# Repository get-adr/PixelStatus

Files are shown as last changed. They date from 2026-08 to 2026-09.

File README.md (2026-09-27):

PixelStatus Logo mit Text - Slogan

# Pixel Status (ESP8266 + MAX7219)

Eine physische Statusanzeige für den Schreibtisch: eine rote 32×8-Punktmatrix aus
vier MAX7219-Modulen, angetrieben von einem ESP8266. Sie zeigt vordefinierte Stati
wie „On Air" oder „In a Call", freien Lauftext, einen Countdown-Timer oder die
Uhrzeit. Angesteuert wird sie wahlweise über die eingebaute **Web-Oberfläche**,
per **MQTT** für bestehende Automatisierungen (inkl. automatischer
**Home-Assistant-Erkennung**), oder direkt per **USB-Kabel** ganz ohne WLAN – alle
drei Wege laufen intern über denselben zentralen Befehls-Dispatcher. Ein
Home-Assistant-Setup ist dafür nicht nötig, lässt sich aber ohne weitere
Konfiguration anschließen.

> Hinweis: Der ESP8266 kann **kein Bluetooth** (nur der ESP32). Drahtlos läuft die
> Übertragung über WiFi; alternativ direkt per USB-Kabel (seriell).

Dieses Dokument führt komplett durch das Projekt: Bauteile & Kosten, das
3D-gedruckte Gehäuse, den Zusammenbau, das eingebaute Minispiel „Pixel Attack",
die MQTT-/Home-Assistant-Anbindung und die Companion-App. Wer nur die Firmware
flashen will, kann direkt zu [Firmware einrichten](#firmware-einrichten) springen.

## Funktionen

- **Presets & freier Text** — On Air, In a Call, Busy, BRB per Klick, oder
  eigener Text (statisch oder scrollend, inkl. Umlaute)
- **Timer & Uhrzeit** — Countdown oder Stoppuhr (pausier-/fortsetzbar),
  NTP-synchronisierte Uhr (läuft auch ohne WLAN per manuell gesetzter Zeit)
- **Pixel Attack** — ein kleines Space-Invaders-artiges Easter-Egg direkt auf
  der Matrix, spielbar per Tastatur oder Handy-Touch (siehe
  [eigenes Kapitel](#pixel-attack-spielen))
- **Darstellung** — persistente Helligkeit, 0°/180°-Drehung für kopfüber
  montierte Geräte, wählbare Scrollrichtung
- **Einschalt-Animationen** — Scan-Wipe, Pixel-Fill, oder ein Fortschrittsbalken,
  der live am echten WLAN-Verbindungsaufbau hängt
- **Zwei Zusatz-LEDs** — unabhängig schaltbar, mit Helligkeitsregler,
  Wechselblinken und automatischer Warnung in den letzten Timer-Minuten
- **Akkubetrieb** — 1S-LiPo mit Ladeüberwachung, Live-Prozentanzeige,
  automatische Dimmung bei niedrigem Ladestand; die Stromversorgung des Geräts,
  kein Zubehör (siehe [Bauteile-Liste](#bauteile-liste--ca-kosten))
- **Sicherer Setup-Hotspot** — findet sich kein bekanntes WLAN, öffnet sich ein
  Hotspot mit geräteeigenem, auf der Matrix angezeigtem Passwort
- **Web-UI** — Deutsch/Englisch umschaltbar, automatischer Dark Mode,
  Live-Diagnoseseite (Heap, CPU-Last, WLAN-Signal, Akkuverlauf)
- **MQTT mit Home-Assistant-Autoconfig** — Entitäten für Status, LEDs, Text,
  Helligkeit und Diagnose erscheinen automatisch in HA (siehe
  [eigenes Kapitel](#mqtt--home-assistant-integration))

PixelStatus Infografic

## Komponenten (Software)

### Firmware (dieses Repo, `src/`)

Läuft komplett eigenständig auf dem ESP8266. Sauber in kleine Klassen mit je
einer Verantwortlichkeit aufgeteilt — Anzeige, LEDs, Netzwerk, Uhrzeit, MQTT,
Web-Server und USB-Protokoll laufen alle über denselben zentralen
Befehls-Dispatcher (`Commands.h`), damit sich neues Verhalten nur an einer
Stelle definieren lässt. WLAN- und MQTT-Zugangsdaten sind zur Laufzeit über das
Web-Portal einrichtbar, ganz ohne Neu-Flashen.

### Companion-App ([`companion/`](companion/README.md))

Eine schlanke Tauri-v2-Tray-App für Windows/macOS: Status per Klick aus dem
Menüleisten-Icon setzen, ohne den Browser aufzumachen. Verbindet sich wahlweise
per WLAN oder direkt per USB-Kabel mit demselben Gerät, erkennt Mikrofonnutzung
automatisch und schaltet selbstständig auf „In a Call".

---

## Bauteile-Liste & ca. Kosten

Alle Preise sind grobe Richtwerte für Einzelstücke auf dem üblichen
Bastler-Marktplatz-Niveau (AliExpress/eBay/Amazon), **ohne Versand** — je nach
Anbieter, Region und Bestellmenge kann es deutlich abweichen. Der Akku ist die
Stromversorgung des Geräts (No-Shift-Topologie, siehe
[Aufbau & Verkabelung](#aufbau--verkabelung)) und damit fester Bestandteil der
Liste, kein Zubehör — ohne ihn läuft nur der ESP8266 selbst über USB (zum
Flashen), die Matrix bleibt dunkel. Vollständige Stückliste inkl. Werkzeug
zusätzlich in [`hardware/wiring/parts-list.md`](hardware/wiring/parts-list.md).

| Teil | Menge | ca. Kosten | Hinweis |
|---|---|---|---|
| ESP8266-Board (Wemos D1 mini oder NodeMCU v2) | 1× | 4–6 € | beide Varianten werden von der Firmware unterstützt |
| MAX7219-LED-Matrix 32×8 (4-in-1-Modul) | 1× | 7–10 € | vier MAX7219 onboard durchgekettet, ein 5-poliger Eingang |
| 1S-LiPo, 2000 mAh | 1× | 7–9 € | 51 × 33 × 10 mm |
| TP4056/TP4057-Lademodul | 1× | 1–2 € | Lader + Schutz-IC |
| LDO-Breakout, 3,3 V | 1× | 1–2 € | Versorgung des ESP8266 aus der Akkuschiene |
| Schiebeschalter, geflanscht (z. B. SS-12F15-G070) | 1× | 1–2 € | Haupt-Ein/Aus, Panel-Mount |
| Diode 1N5817, Elko 1000 µF/10 V, Widerstände 100 kΩ/220 kΩ, Keramik-Cs | je 1–2× | 2–3 € | Rückspeisungsschutz, Pufferung, Akku-Spannungsteiler |
| USB-Kabel (Micro-USB oder USB-C, je nach Board) | 1× | 3–5 € | zum Flashen und Laden |
| Dünne Litze / Jumper-Kabel | ein paar | 1–2 € | Brücken zwischen den Modulen |
| Gehäuse (3D-Druck, PLA) | 1 Satz | 2–3 € | reine Filamentkosten, siehe [Gehäuse-Kapitel](#gehäuse-3d-modell--druck) |
| 2× 5-mm-LED + Vorwiderstand (220–330 Ω) | je 1 Satz | ~1 € | optional, aber von der Firmware vorgesehen (Zusatz-LEDs) |

**Summe: ca. 32–45 €**

### Werkzeug (kein Verbrauchsmaterial, meist schon vorhanden)

Lötkolben + Lötzinn, Multimeter (Pflicht vor jedem Einschalten), Seitenschneider
+ Abisolierzange, Schrumpfschlauch oder Isolierband, ein kleiner Schraubendreher
für die Schalter-Befestigung. Details siehe Stückliste oben.

---

## Gehäuse: 3D-Modell & Druck

Das Gehäuse ([`hardware/case/`](hardware/case/)) ist ein **parametrisches
OpenSCAD-Modell** — `case.scad` — entworfen und getestet auf einem **Bambu Lab
P1S in PLA**. Zwei Hauptteile plus ein kleines Zubehörteil:

- **`body`** — Front-Blende und Wanne in einem Stück; alle Komponenten werden
  von **hinten** eingesetzt.
- **`cover`** — Rückdeckel, klippt/reibt auf den Body.
- **`feed_plug`** — kleiner Verschluss-Stopfen für die Kabeldurchführung, durch
  die das Steuerkabel (USB) nach außen geführt wird.

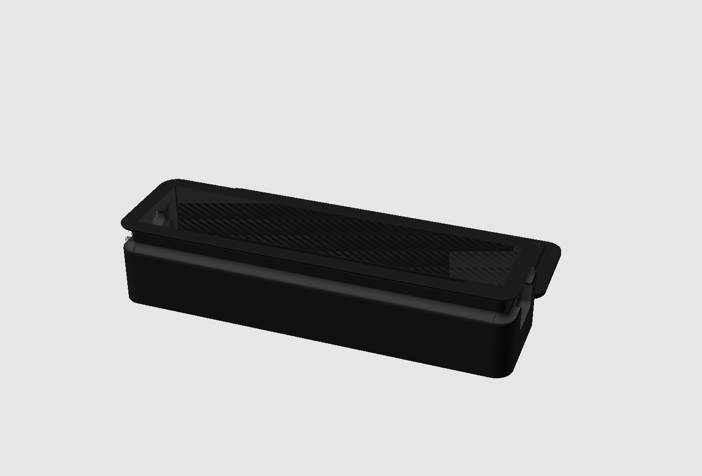
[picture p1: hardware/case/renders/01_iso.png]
Gehäuse-Gesamtansicht


### Ein paar Design-Entscheidungen

- **Druckorientierung**: Der Body druckt mit dem **LED-Fenster nach unten**
  auf dem Druckbett — spart Stützstrukturen genau dort, wo sie die Optik am
  meisten stören würden. Der schräge Ladeteil-Halter (45°) druckt dabei ohne
  eigene Stützen mit.
- **Ladeteil-Halterung**: Eigens konstruierter 45°-Schräghalter — alles hinter
  der Matrix muss strikt hinter deren Bautiefe bleiben, sonst kollidiert es.
- **Kabelaufwicklung**: Ein eingelassener Kragen mit rundem Nutprofil, dazu
  eine Keyhole-Durchführung mit Klemmschlitz als Zugentlastung und dem
  steckbaren `feed_plug` als Verschluss.
- **USB-C-Öffnung**: Stadionform statt scharfem Rechteck, mit Senkung außen
  für den Steckerkörper.
- **Status-LED-Bucht**: Gehäuse eigens verbreitert, damit zwei 5-mm-LEDs im
  Presssitz neben der Matrix Platz finden.
- **Aufstellung**: Bewusst kein Standfuß, keine Wandhalterung — ein
  kompakter, freistehender Baukörper.

| Innenansicht (Ladeteil-Halter) | Halbschnitt | Kabelaufwicklung |
|---|---|---|
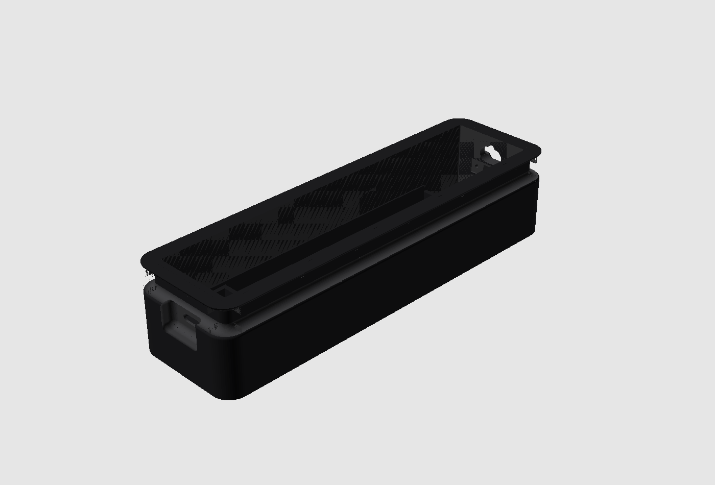
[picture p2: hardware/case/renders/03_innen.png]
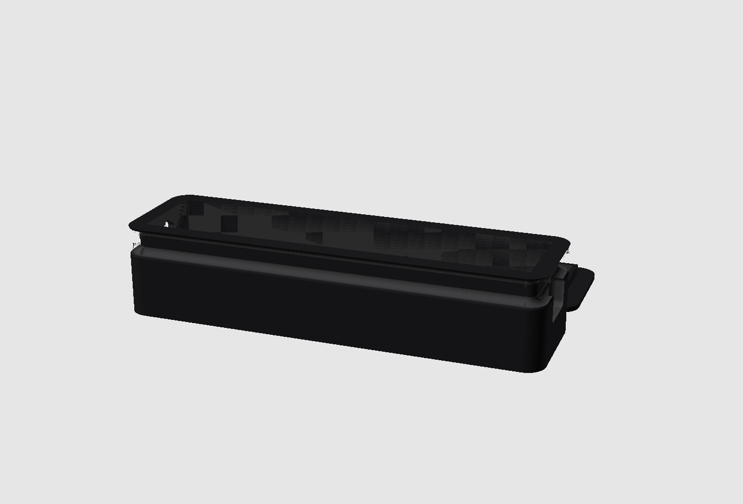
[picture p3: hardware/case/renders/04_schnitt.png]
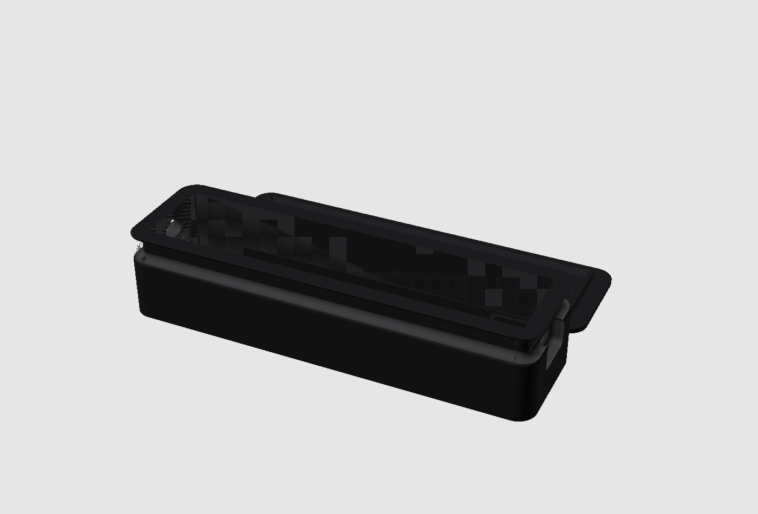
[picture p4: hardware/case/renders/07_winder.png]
|  |  |  |

### Selbst drucken

**Fertige STL-Dateien** liegen schon bereit unter
[`hardware/case/stl/`](hardware/case/stl/) (`body.stl`, `cover.stl`,
`feed_plug.stl`, alternativ als `case.3mf`) — direkt in den Slicer laden, kein
OpenSCAD nötig, solange die Standardmaße passen.

1. **Slicer-Einstellungen**: PLA, Standard-Layerhöhe (0,2 mm reicht), **keine
   Stützstrukturen nötig**, wenn der Body wie oben beschrieben orientiert
   gedruckt wird (bei den meisten Slicern automatisch erkannt, da die flache
   Frontseite dann auf dem Bett liegt).
2. **Passprobe vor dem Verkleben**: Matrix probeweise in den Slot schieben,
   Lademodul in die Tasche legen, Deckel auflegen — noch nichts fest
   verbauen. Bei Klemmen lieber mit Schleifpapier nacharbeiten statt zu
   forcieren (PLA splittert sonst).

**Eigene Maße messen (nur bei abweichenden Bauteilen nötig)**: `case.scad`
markiert alle kritischen Maße (Matrix-Abmessungen, Akku-Größe, Lademodul,
USB-C-Buchse …) mit `(*)` am Zeilenende. Weichen die eigenen Bauteile von den
hinterlegten Werten ab, dort mit dem Messschieber nachmessen, anpassen und neu
rendern:

```bash
# OpenSCAD installieren (einmalig)
brew install openscad          # oder von openscad.org

# STL exportieren (aus hardware/case/)
openscad -o stl/body.stl -D 'part="body"' case.scad
openscad -o stl/cover.stl -D 'part="cover"' case.scad
openscad -o stl/feed_plug.stl -D 'part="feed_plug"' case.scad

# Vorschau-Renderbilder neu erzeugen (wie oben im Dokument)
./render.sh
```

---

## Aufbau & Verkabelung

Die Matrix hängt direkt an der Akkuschiene (No-Shift-Topologie, ≤ ~4,5 V —
läuft ohne Pegelwandler an der 3,3-V-SPI des ESP8266), der ESP8266 selbst über
einen LDO+Diode am selben Zweig. **USB am D1 mini allein reicht nicht**, um das
Gerät normal zu betreiben: ohne Akku bzw. bei ausgeschaltetem Hauptschalter
läuft darüber nur der ESP selbst (zum Flashen/Debuggen) — die Matrix bleibt
dunkel, weil ihre Stromversorgung am abgeschalteten Akku-Zweig hängt (eine
Schottky-Diode verhindert dabei sogar ausdrücklich, dass USB-Strom in diesen
Zweig zurückfließt). Für den Normalbetrieb sind Akku und Hauptschalter also
notwendig, nicht optional.

### Signal-Pins (SPI)

| MAX7219 | ESP8266 (NodeMCU / D1 mini) |
|---|---|
| VCC | Akkuschiene (SYS, **nicht** an einen 5-V-Pin) |
| GND | Stern-Masse |
| DIN | D7 / GPIO13 (MOSI, HW-SPI) |
| CLK | D5 / GPIO14 (SCK, HW-SPI) |
| CS | D8 / GPIO15 (`CS_PIN`) |

DIN und CLK liegen fest auf den Hardware-SPI-Pins. CS ist in `include/config.h`
frei wählbar. Die zwei Zusatz-LEDs hängen an `LED_PIN_1`/`LED_PIN_2` (Default
GPIO4/D2 und GPIO5/D1) über je einen Vorwiderstand gegen GND.

### Vollständige Montageanleitung

Für die komplette Verkabelung gibt es eine eigene, ausführliche Anleitung mit
Verkabelungsdiagramm und nummerierter Lötreihenfolge:
[`hardware/wiring/wiring-sheet.html`](hardware/wiring/wiring-sheet.html)
(im Browser öffnen). Kurzfassung der fünf Phasen:

1. **Gehäuse vorbereiten** — Druckgrat entfernen, Passprobe, Schalter
   final verschrauben.
2. **Löten (Werkbank)** — acht Schritte in fester Reihenfolge: LDO →
   Rückspeisungsschutz-Diode → Akku-Spannungsteiler (für die
   Prozentanzeige) → Lademodul → Matrix-Stützkondensatoren → Hauptschalter
   in die Leistungsleitung → Stern-Masse zusammenführen → SPI verdrahten.
3. **Bench-Test** — **außerhalb** des Gehäuses, mit dem Multimeter
   gegenprüfen (Kurzschluss, Diodenpolung, Stern-Masse), bevor überhaupt der
   Akku angeschlossen wird. Fehler sind hier leicht zu finden; im
   geschlossenen Gehäuse wird jede Korrektur mühsam.
4. **Endmontage ins Gehäuse** — siehe unten.
5. **Firmware-Erstkonfiguration** — WLAN über den Setup-Hotspot einrichten,
   `BATTERY_MONITOR_ENABLED` aktivieren, neu flashen.

### Wie alles ins Gehäuse kommt

Reihenfolge für die Endmontage (Body wird von **hinten** befüllt):

1. Nochmals auf Kurzschluss/Wackelkontakt prüfen, bevor irgendetwas fest im
   Gehäuse verschwindet.
2. **Matrix von hinten in den Slot schieben**, bis zum Anschlag an der
   Lader-seitigen Wand — sitzt im Sandwich zwischen Front und Deckel, kein
   Kleben nötig.
3. **Zusatz-LEDs von hinten in die Front-Löcher drücken** (Presssitz durch
   die LED-Bucht).
4. **Lademodul in die Tasche legen** — USB-C-Buchse sitzt in der
   Stirnwand-Öffnung, die Platine wird über die verlöteten Kabel gehalten.
5. **ESP8266 + restliche Elektronik** (LDO, Diode, Spannungsteiler) lose im
   Rückraum platzieren, offene Lötstellen mit Schrumpfschlauch isolieren.
6. **LiPo-Akku einlegen**, flach im Rückraum, mit kurz genug bemessenem Kabel
   zum Lademodul (Zugentlastung).
7. **Steuerkabel durch die Durchführung fädeln**, in den Klemmschlitz
   drücken, restliche Länge in der umlaufenden Nut aufwickeln, danach den
   `feed_plug` im Presssitz einsetzen.
8. **Deckel aufsetzen** — Reib-/Klipplippe, gleichmäßig andrücken.
9. **Funktionstest im geschlossenen Gehäuse**: Schalter Ein, Matrix und beide
   LEDs prüfen; danach Schalter Aus + Laden testen (Gerät bleibt dabei aus,
   USB-C am Lader lädt trotzdem).

| USB-C-Öffnung | Kabeldurchführung + Stopfen | Status-LED-Bucht |
|---|---|---|
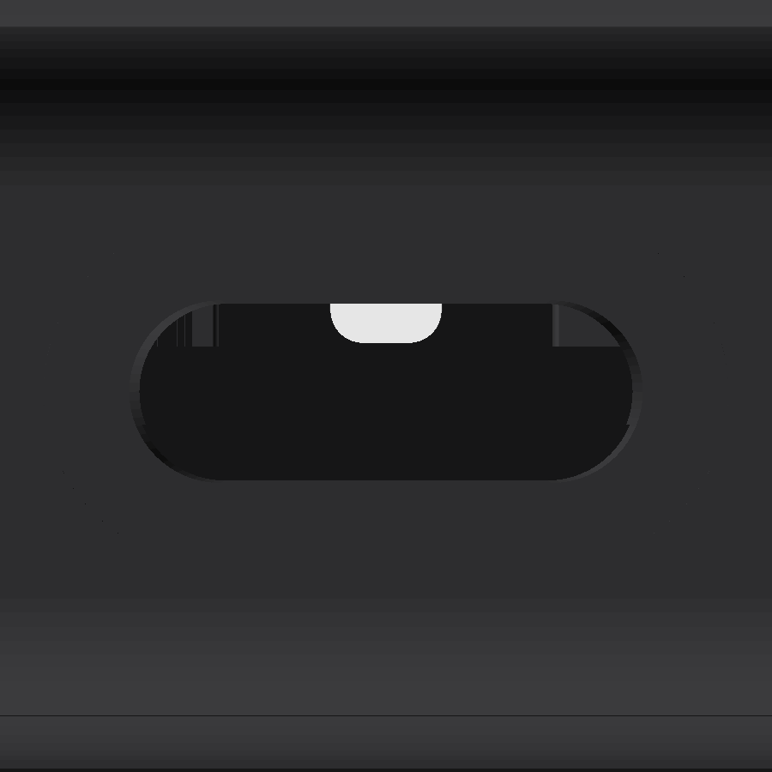
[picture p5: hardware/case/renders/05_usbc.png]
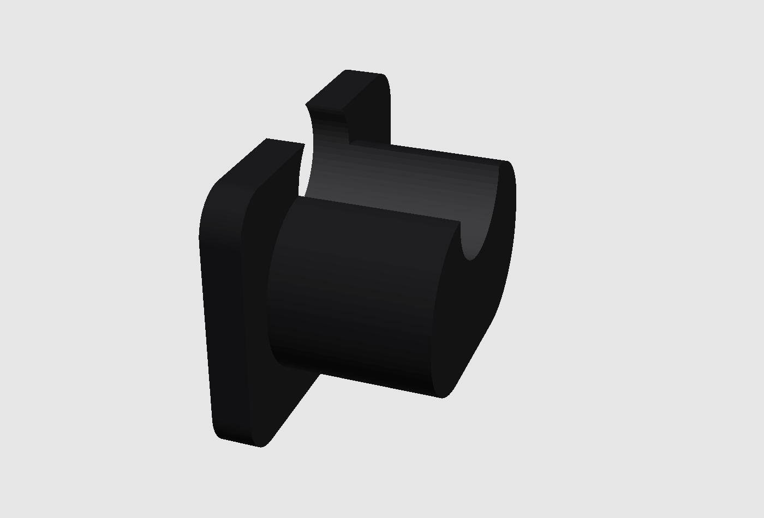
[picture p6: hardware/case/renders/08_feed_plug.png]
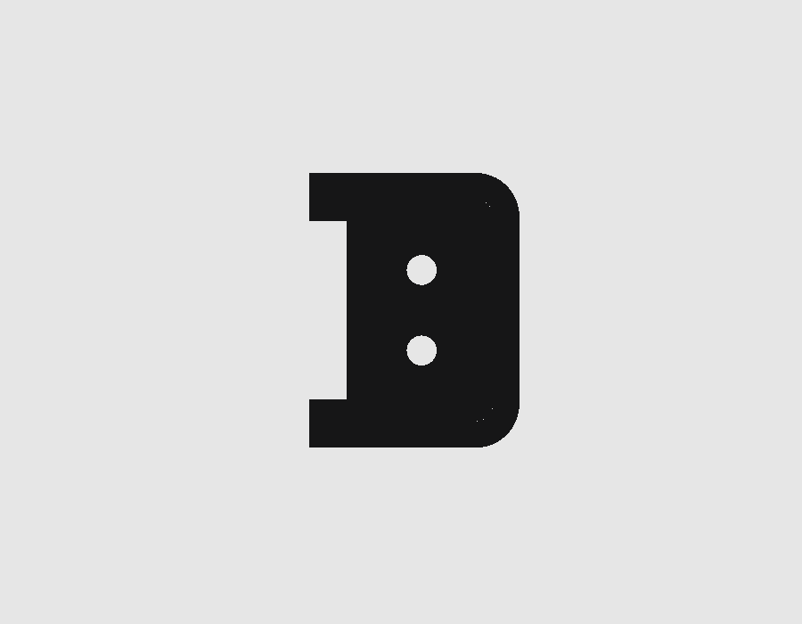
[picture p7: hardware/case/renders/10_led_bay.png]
|  |  |  |

## Firmware einrichten

```bash
# PlatformIO installieren (einmalig)
brew install platformio          # oder: pip install platformio

# Konfiguration anlegen und WiFi/MQTT eintragen
cp include/config.example.h include/config.h

# Bauen, flashen, Logs ansehen
pio run                          # kompilieren
pio run -t upload                # auf den ESP8266 flashen
pio device monitor               # serielle Ausgabe (115200 Baud)
```

Für den Wemos D1 mini: `pio run -e d1_mini -t upload`.

### Apple Silicon: Bauen im Container

Die Xtensa-Toolchain für den ESP8266 gibt es für macOS **nur als x86-Binary** —
weder der ESP8266-Arduino-Boardindex noch die PlatformIO-Registry bieten einen
arm64-Build an, und das Projekt dahinter (`esp-quick-toolchain`) hat seit Anfang
2023 kein Release mehr. Auf Apple Silicon lief das bisher über Rosetta; ohne
Rosetta scheitert `pio run` mit „Bad CPU type in executable". Für Linux gibt es
die Toolchain dagegen als `aarch64`-Build — in einem arm64-Linux-Container läuft
sie nativ, ohne Emulation:

```bash
brew install --cask orbstack      # oder Docker Desktop / colima
brew install esptool              # nativer Flasher für macOS

tools/build-docker.sh             # baut d1_mini im Container
tools/build-docker.sh nodemcuv2   # andere Env
tools/flash.sh                    # flasht die gebaute .bin vom Mac aus
pio device monitor                # Logs weiterhin nativ (reines Python)
```

Gebaut wird im Container, **geflasht vom Mac** — USB-Geräte lassen sich auf
macOS nicht in die Linux-VM durchreichen, der Upload braucht aber auch keinen
Compiler. Die fertige `.bin` landet über das gemountete Projektverzeichnis
direkt im Arbeitsverzeichnis. Framework und Toolchain liegen in einem benannten
Docker-Volume, nur der erste Lauf lädt sie herunter.

Zum Flashen reicht das USB-Kabel am D1 mini; für den eigentlichen Betrieb
danach Akku anschließen und den Hauptschalter einschalten (siehe
[Aufbau & Verkabelung](#aufbau--verkabelung)) — die Matrix bleibt sonst dunkel.
Nach dem Flashen scrollt das Display die IP-Adresse. Bedienseite öffnen unter
`http://pixelstatus.local` oder über die angezeigte IP. Findet sich beim ersten
Boot kein bekanntes WLAN, öffnet das Gerät selbst einen Setup-Hotspot mit
eigenem Passwort (wird auf der Matrix angezeigt) — WLAN-Zugangsdaten dann unter
`http://192.168.4.1/wifi` eintragen.

PixelStatus - Montiert

---

## Pixel Attack spielen

Ein kleines Space-Invaders-artiges Easter-Egg direkt auf der 32×8-Matrix: ein
Verteidiger am rechten Rand weicht Angreifern aus, die von links hereinlaufen
und beschossen werden. Rein clientseitig über die Web-UI gesteuert (keine
physischen Tasten am Gerät, kein MQTT/USB-Befehl dafür vorgesehen).

### Am Rechner (Browser, Tastatur)

Auf der Startseite die Kachel **„Pixel Attack"** öffnen, dann **„Start"**
klicken. Steuerung wahlweise über die Panel-Buttons (▲ / ▼ / ●) oder direkt per
Tastatur, solange das Panel geöffnet ist:

| Taste | Aktion |
|---|---|
| ↑ / ↓ (Pfeiltasten) | Verteidiger hoch/runter bewegen |
| Leertaste | Schießen (bis zu 5 Schüsse gleichzeitig unterwegs) |
| B | Bombe zünden (2 pro Runde, sprengt alle sichtbaren Angreifer — an die zwei physischen Zusatz-LEDs gekoppelt, die anzeigen, wie viele Bomben noch verfügbar sind) |

Punkte gibt's pro Treffer, größere Angreifer brauchen mehrere Treffer. Bei 0
Leben läuft „GAME OVER", der erreichte Score und der Highscore als
Lauftext über die Matrix.

### Am Handy (Touch-Steuerung)

Im Spiel-Panel gibt es zusätzlich einen Button **„Touch-Steuerung"**, der die
eigene Seite `/play` in einem neuen Tab öffnet — für Handys im **Querformat**
gedacht: große Daumen-Buttons links (Hoch/Runter) und rechts (Feuer/Bombe), in
der Mitte Score/Leben/Bomben/Highscore plus ein Neustart-Button. Im
Hochformat blendet die Seite einen Hinweis zum Drehen ein.

Die Seite nutzt dieselbe API wie das Desktop-Panel — keine gesonderte
Konfiguration nötig, einfach auf demselben WLAN mit dem Handy öffnen (URL vom
Gerät wie oben, z. B. `http://pixelstatus.local/play`).

Pixel_Attack

---

## MQTT & Home-Assistant-Integration

### MQTT-Grundlagen

MQTT lässt sich zur Laufzeit über das Web-Portal (`/settings` → Tab „MQTT")
ein-/ausschalten und konfigurieren — Broker-Host, Port, Zugangsdaten und
Basis-Topic, alles ohne Neu-Flashen. Befehle gehen an
`<base>/cmd/<aktion>` (Basis-Topic frei wählbar, Default `pixelstatus`):

```
pixelstatus/cmd/preset      onair
pixelstatus/cmd/text        Hallo Welt
pixelstatus/cmd/scroll      Langer Lauftext
pixelstatus/cmd/timer       300        # Countdown in Sekunden; "up"; "pause"; "resume"; "stop"
pixelstatus/cmd/brightness  8
pixelstatus/cmd/led         1 on       # "1|2|both" + "off|on|blink"
pixelstatus/cmd/clear
```

Der aktuelle Gesamtzustand wird **retained** nach `pixelstatus/state`
veröffentlicht — auch bei Änderungen über die Web-UI oder USB, nicht nur bei
MQTT-Kommandos. Ein `pixelstatus/health`-Topic ergänzt Diagnosewerte (freier
Speicher, WLAN-Signal, Laufzeit, optional Akkuspannung/-prozent). MQTT lässt
sich in `include/config.h` per `MQTT_ENABLED false` auch als Compile-Time-
Default ganz abschalten.

### Automatische Home-Assistant-Erkennung (MQTT Discovery)

Sobald MQTT aktiv und mit einem Broker verbunden ist, meldet sich das Gerät
automatisch bei Home Assistant per [MQTT-Discovery](https://www.home-assistant.io/integrations/mqtt/#mqtt-discovery) —
**keine YAML-Konfiguration, keine manuellen Entitäten nötig.** Alles erscheint
gruppiert unter einem gemeinsamen Gerät „pixelstatus":

| Entität | Typ | Beschreibung |
|---|---|---|
| Status | Select | Presets: On Air, Call, Busy, BRB, Free, Off |
| Text | Text | eigener, frei einstellbarer Anzeigetext |
| Matrix-Helligkeit | Number | 0–15 Stufen |
| LED 1 / LED 2 | Light | An/Aus, Helligkeit (0–15), Effekt „Blinken" |
| Freier Speicher, WLAN-Signal, Laufzeit | Sensor | Diagnosewerte |
| Akkuspannung, Akkustand | Sensor | nur sichtbar, wenn die optionale Akku-Hardware aktiviert ist |
| Countdown-Warnung | Binary Sensor | aktiv während der letzten Timer-Minuten |

Alle Entitäten (außer dem Status-Select, der bewusst ohne Rückkanal arbeitet,
da sich der Anzeigeinhalt nicht immer eindeutig auf einen Preset-Namen
zurückrechnen lässt) zeigen den **echten Live-Zustand** — egal ob die letzte
Änderung über Home Assistant, die Web-UI, die Companion-App oder USB kam. Das
Gerät meldet sich zudem über ein MQTT-Last-Will automatisch als „nicht
verfügbar", falls die Verbindung ungeplant abreißt (Stromausfall, WLAN weg).

**Einrichtung**: einfach unter `/settings` → „MQTT" den eigenen Broker
eintragen (Host, Port, ggf. Zugangsdaten) und speichern — Home Assistant
übernimmt den Rest automatisch, sobald es denselben Broker kennt.

---

## Companion-App

Eine schlanke Tray-/Menüleisten-App für **Windows und macOS**
([`companion/`](companion/README.md), gebaut mit Tauri v2): Status per Klick
setzen, ohne den Browser aufzumachen. Läuft komplett unabhängig von MQTT/Home
Assistant — spricht direkt mit dem Gerät.

### Verbindungsoptionen

Umschaltbar in den Einstellungen der App, wird dort dauerhaft gespeichert:

- **WiFi (HTTP)** — verbindet sich wie die Web-UI über das lokale Netzwerk,
  Standard-Host `pixelstatus.local` (oder die IP direkt eintragen). Funktioniert
  von überall im selben WLAN.
- **USB-Kabel (seriell)** — spricht dasselbe Protokoll wie der Web-API-Weg,
  aber direkt über die USB-Verbindung, ganz ohne WLAN. Seriellen Port aus einer
  Liste wählen (↻ aktualisiert sie); für Windows wird der CH340-Treiber des
  D1 mini benötigt (macOS bringt ihn meist schon mit), die App zeigt dazu einen
  Hinweis mit Download-Link. Das reine Öffnen des Ports löst am D1 mini **keinen**
  Reset aus — Steuerung läuft also ohne Neustart des Geräts.

Beide Wege nutzen intern dieselben Aktionen wie `src/Commands.h` — welcher Weg
gerade aktiv ist, ändert am Verhalten nichts.

### Bedienung

- **Tray-Menü**: Presets direkt anklickbar (On Air, In a Call, Busy, BRB,
  Uhrzeit, Aus), der aktive Status ist mit einem Häkchen markiert — auch wenn
  er von woanders (Web-UI, MQTT, Home Assistant) gesetzt wurde, die App pollt
  den Gerätezustand im Hintergrund mit.
- **Fenster** (über „Einstellungen…" im Tray-Menü): zusätzlich eigener Text,
  Timer (Play/Pause/Stopp, Countdown oder Hochzählen), Matrix- und
  LED-Helligkeit, sowie sämtliche Geräte-Einstellungen (System/LED/WiFi/MQTT) —
  dasselbe `get*`/`cfg*`-Protokoll wie im Web-Portal, funktioniert also über
  **beide** Verbindungsarten. Fenster-Schließen versteckt nur (App bleibt im
  Tray), Beenden über das Tray-Menü.
- **Automatischer Status**: Checkbox „Automatisch „In a Call" bei
  Mikrofonnutzung" — die App erkennt Mikrofonzugriff (macOS über CoreAudio ohne
  Berechtigungsabfrage, Windows über die Registry) und schaltet selbstständig
  um; beim Auflegen kehrt der zuvor manuell gesetzte Status zurück.
- **Sprache**: Deutsch/Englisch umschaltbar, gilt auch fürs Tray-Menü.

### Installation

Vorgefertigte Installer (Windows x64/ARM64, macOS) baut die GitHub-Action bei
jeder Änderung unter `companion/` automatisch als Artifact. Alternativ selbst
bauen:

```bash
cd companion
npm install
npm run tauri icon pfad/zu/icon.png   # einmalig: Icons erzeugen
npm run tauri dev                      # Entwicklungsmodus
npm run tauri build                    # Installer: .dmg / .exe
```

Details (Voraussetzungen, macOS-Gatekeeper-Hinweis „ist beschädigt" bei
unsignierten Downloads, Projektaufbau) siehe
[`companion/README.md`](companion/README.md).

---

## Weitere Steuerwege (Referenz)

### Web-API (HTTP GET)

| Endpunkt | Beispiel |
|---|---|
| Generisch | `/api/cmd?action=preset&value=onair` (von der Companion-App genutzt) |
| Preset | `/api/preset?name=onair` (onair, call, busy, brb, dnd, free, away, off) |
| Text | `/api/text?msg=Hallo&scroll=1` |
| Timer | `/api/timer?seconds=300&dir=down` · `?dir=up` · `?stop=1` |
| Helligkeit | `/api/brightness?level=8` (0–15) |
| Leeren | `/api/clear` |
| Status | `/api/state` (JSON) |

Uhrzeit zeigen: `/api/cmd?action=clock&value=on`. Zeitquelle (NTP an/aus,
Server) **und Zeitzone** stehen im System-Tab der Einstellungen; `NTP_TZ`/
`NTP_SERVER` in `config.h` sind nur die Startwerte. Übertragen wird immer ein
UTC-Zeitstempel – die eingestellte Zone bestimmt, was die Matrix daraus macht.

### USB (seriell, 115200 Baud)

Ohne WiFi steuerbar – zeilenweise Befehle `<aktion> <wert>` auf den USB-Port,
Antwort ist eine JSON-Statuszeile:

```
preset onair
text Hallo Welt
timer 300            # Countdown in Sekunden; "up"; "pause"; "resume"; "stop"
clock on
settime 1719600000   # Systemzeit setzen (Uhr ohne WiFi/NTP)
brightness 8
clear
```

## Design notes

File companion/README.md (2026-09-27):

# Pixel Status Companion

Tray-/Menüleisten-App (Windows + macOS) zum Steuern des ESP8266-Pixel-Status-Displays.
Gebaut mit **Tauri v2** (Rust-Backend + HTML/JS-Frontend). Steuert das Display
wahlweise über **WiFi (HTTP)** oder das **USB-Kabel (seriell)** – umschaltbar in
den Einstellungen.

## Voraussetzungen

- **Node.js** (vorhanden) – liefert die Tauri-CLI über npm.
- **Rust** – noch installieren:
  ```bash
  curl --proto '=https' --tlsv1.2 -sSf https://sh.rustup.rs | sh
  ```
- Plattform-Abhängigkeiten für Tauri v2 siehe https://tauri.app/start/prerequisites/
  (macOS: Xcode Command Line Tools; Windows: WebView2 + MSVC Build Tools).

## Icons (einmalig vor dem ersten Build)

Tauri bettet App-/Tray-Icons ein, daher müssen sie existieren. Aus einem
beliebigen quadratischen PNG generieren:

```bash
npm install
npm run tauri icon pfad/zu/icon.png   # erzeugt src-tauri/icons/*
```

## Entwickeln & Bauen

```bash
npm install
npm run tauri dev      # App im Entwicklungsmodus starten
npm run tauri build    # Installer bauen: macOS .dmg / Windows .exe (nsis)
```

### Abhängigkeiten und Dependabot

Die App wird ausschließlich für **Windows und macOS** gebaut (siehe Workflow
unten). Tauri zieht seine Linux-Abhängigkeiten (`gtk`, `glib`, `webkit2gtk`,
`libappindicator` …) trotzdem in `Cargo.lock`, sie werden aber nur für
Linux-Ziele überhaupt kompiliert:

```bash
cargo tree -e normal -i glib --target x86_64-unknown-linux-gnu   # Treffer: gtk 0.18 -> tao/muda/tray-icon
cargo tree -e normal -i glib --target aarch64-apple-darwin       # "nothing to print"
```

Eine Dependabot-Meldung zu einem dieser Crates betrifft daher keinen
ausgelieferten Build. Sie lässt sich zudem nicht durch ein Update auflösen:
Tauri 2.x hängt über `tao`/`muda`/`tray-icon` fest an `gtk` 0.18 (gtk3-rs), das
seinerseits `glib` 0.18 vorgibt — ein Sprung auf `glib` 0.20 setzt ein
Upstream-Update von Tauri voraus. Vor dem Schließen einer solchen Meldung beide
`cargo tree`-Aufrufe oben wiederholen, statt die Einschätzung fortzuschreiben.

## Installation vorgefertigter Builds (GitHub Actions)

Der Workflow `.github/workflows/companion-build.yml` baut bei jedem Push nach
`main` (mit Änderungen unter `companion/`) automatisch Installer für Windows
x64/ARM64 und macOS als Artifacts.

**macOS: „ist beschädigt und kann nicht geöffnet werden“** – kein echter
Schaden, sondern Gatekeeper: die App ist **nicht mit einer Apple-Developer-ID
signiert/notarisiert**, und der Browser markiert heruntergeladene Dateien mit
dem Quarantäne-Flag (`com.apple.quarantine`). Statt der eigentlich
zutreffenden Meldung „von nicht verifiziertem Entwickler“ zeigt macOS in
diesem Fall fälschlich „beschädigt“. Fix nach der Installation:

```bash
xattr -cr "/Applications/Pixel Status Companion.app"
```

Danach lässt sich die App normal öffnen. Muss nach jedem neuen Download eines
Builds wiederholt werden. Dauerhaft beheben ließe sich das nur durch Code-
Signing + Notarisierung (Apple-Developer-Programm, 99 $/Jahr, plus
Zertifikat-Secrets im CI-Workflow) – für den privaten Gebrauch nicht
eingerichtet.

## Bedienung

- Die App lebt in der Menüleiste/Tray. Das Menü bietet die Presets direkt
  (On Air, In a Call, Busy, BRB, Uhrzeit, Aus) sowie „Einstellungen…“.
- Das Fenster (über „Einstellungen…“) bietet zusätzlich freien Text, Timer,
  Helligkeit und die Verbindungseinstellungen. Fenster-Schließen versteckt nur
  (App bleibt im Tray); Beenden über das Tray-Menü.
- **Verbindung** in den Einstellungen: WiFi (Host, Standard `pixelstatus.local`)
  oder USB (seriellen Port wählen, ↻ aktualisiert die Liste). Wird im
  App-Config-Verzeichnis persistiert.
- **Auto-Status:** In den Einstellungen lässt sich die automatische Statusquelle
  wählen. Bei Mikrofon-Nutzung pollt die App die Mikrofonnutzung und schaltet
  bei Aktivität auf
  „In a Call"; beim Auflegen wird der zuvor manuell gesetzte Status
  wiederhergestellt (sonst geleert).
  - macOS: über CoreAudio (`kAudioDevicePropertyDeviceIsRunningSomewhere`) —
    erkennt jede Mikrofonnutzung, **ohne** Mikrofon-Berechtigung anzufordern.
  - Windows: über die Registry (`CapabilityAccessManager\ConsentStore`).

### Microsoft-Teams-Präsenz

Als automatische Statusquelle kann „Microsoft Teams“ gewählt werden. Die App
verwendet Microsoft Graph (`GET /me/presence`) und bietet zwei Login-Methoden
(Einstellungen → „Login-Methode“):

- **Browser (empfohlen, Default):** Authorization-Code-Flow mit PKCE. Die App
  hört kurz auf `127.0.0.1:8939`, öffnet den Systembrowser auf der Anmelde-URL
  und tauscht den zurückgelieferten Code gegen Tokens ein. Die passende
  Loopback-URI muss in der App-Registrierung eingetragen sein. Ein erneuter
  Klick auf „Anmelden“ bricht einen noch wartenden Vorgang ab und gibt den
  Port sofort wieder frei.
- **Device-Code:** gerätecodebasierter Login (Code im Browser eingeben), der in
  vielen Tenants gesperrt ist — als Option für Tenants, die ihn erlauben.

Dafür muss eine Microsoft-Entra-App-Registrierung als Public Client mit
delegierter Berechtigung `Presence.Read` angelegt und deren Client-ID
eingetragen werden; als Tenant ist `organizations` für Arbeits-/Schulkonten
voreingestellt. Die Registrierung lässt sich einmalig mit dem Helper-Skript im
Repo anlegen (läuft selbst per Browser-Login):

```powershell
pwsh tools/New-PixelStatusAppRegistration.ps1 -InstallModules
```

Es legt die App an, setzt `Presence.Read` und die Loopback-URI und gibt die
Client-ID aus, die in die Einstellungen eingetragen wird. Für das Erstellen und
Aktualisieren von App-Registrierungen gibt es keinen passenden delegierten
`Application.ReadWrite.OwnedBy`-Scope; der Helper benötigt deshalb
`Application.ReadWrite.All`. Es werden keine weiteren Graph-Berechtigungen
angefordert. Die Anmeldung muss von einem Konto erfolgen, das im Tenant
App-Registrierungen verwalten darf.

Access- und Refresh-Tokens werden nicht in `settings.json` gespeichert, sondern
im nativen Credential Store des Betriebssystems. `InACall`/`InAMeeting` werden
zu „In a Call“, `Busy` zu „Busy“, `DoNotDisturb` zu „DND“, `BeRightBack` zu
„BRB“, `Away` zu „Away“ und `Available` zu „Frei“ (Matrix: `FREE`) abgebildet.

Die Präsenz wird im Hintergrund alle 10 s abgefragt; ans Display geht nur eine
Änderung. Ist Teams als Quelle gespeichert, zeigt das Fenster über den
Status-Buttons Login-Status und aktuelle Präsenz und markiert den zugeordneten
Button mit einem „Teams“-Badge (unabhängig von der grünen Markierung, die den
tatsächlichen Display-Inhalt zeigt). Das Fenster nutzt dafür das Ergebnis der
Hintergrundabfrage und fragt Graph nicht zusätzlich ab.
Schlägt eine Graph-Abfrage fehl (z. B. bei beendetem Teams oder
Netzwerkproblemen), meldet Graph `Offline` oder keinen Verfügbarkeitswert,
schaltet die App die Matrix sofort einmalig aus und zeigt einen Hinweis.
Weitere Fehl- bzw. Offline-Meldungen überschreiben manuelle Bedienung nicht;
sobald wieder eine zuordenbare Teams-Präsenz vorliegt, zeigt die Matrix deren
Status. Andere unbekannte Werte lassen die Anzeige unverändert.

## Aufbau

| Datei | Zweck |
|---|---|
| `src/` | Frontend (index.html, main.js, styles.css), nutzt globales `window.__TAURI__` |
| `src-tauri/src/lib.rs` | Tray-Menü, Tauri-Commands, App-State |
| `src-tauri/src/transport.rs` | HTTP- und USB-Seriell-Versand, Port-Liste |
| `src-tauri/src/settings.rs` | Laden/Speichern der Einstellungen als JSON |
| `src-tauri/src/mic.rs` | Mikrofon-Nutzungserkennung (macOS/Windows) für den Auto-Status |

Alle Befehle gehen am Ende auf den Firmware-Endpunkt `/api/cmd?action=&value=`
(HTTP) bzw. die serielle Zeile `<action> <value>` – dieselben Aktionen wie in
`../src/Commands.h`.

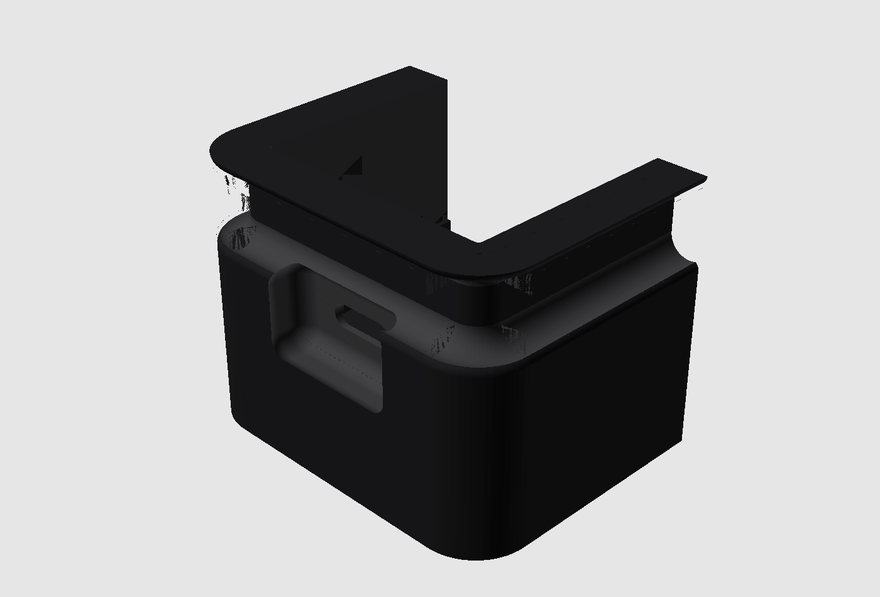
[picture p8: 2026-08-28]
hardware/case/renders/09_coupon_chg.png

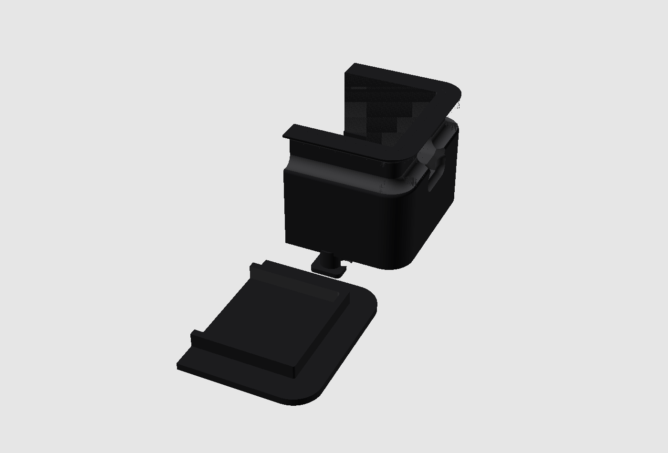
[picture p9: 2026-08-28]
hardware/case/renders/06_coupon.png

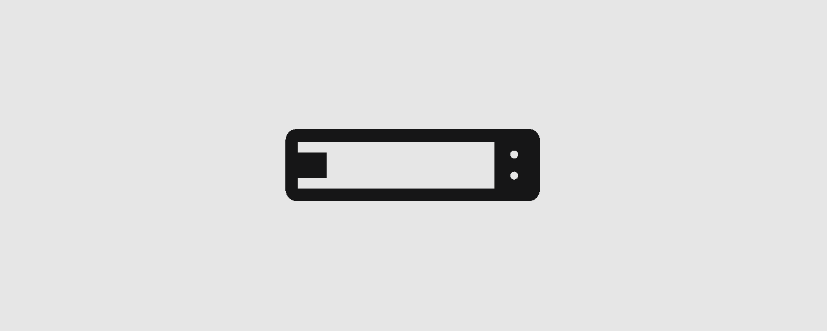
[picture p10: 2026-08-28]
hardware/case/renders/02_front.png

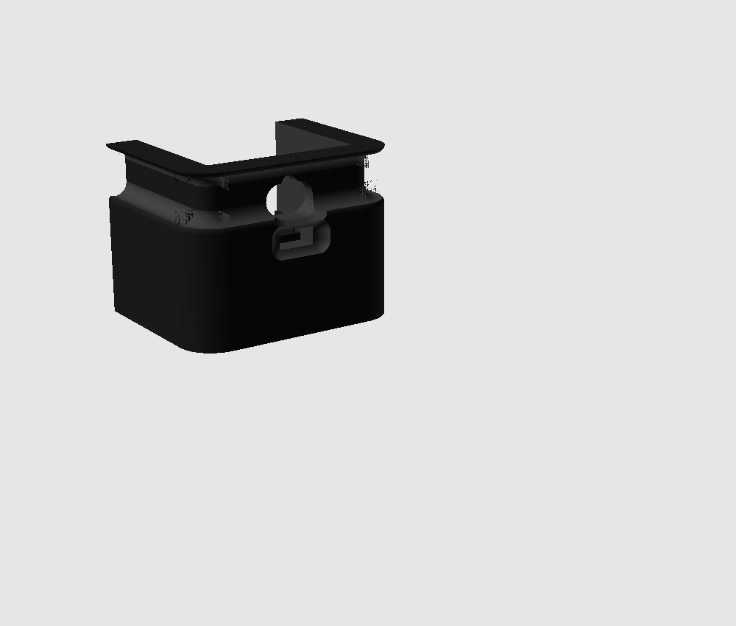
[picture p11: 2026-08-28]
hardware/case/renders/11_switch.png

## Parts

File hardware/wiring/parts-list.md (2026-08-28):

# Teileliste — Akkubetrieb (1S-LiPo, No-Shift-Topologie)

Vollständige Teileliste für den Akkubetrieb. Montageanleitung + Verkabelungsblatt:
siehe `hardware/wiring/wiring-sheet.html`.

## Vorhanden (vollständig)

| Teil | Menge | Zweck | Details |
|---|---|---|---|
| 1S-LiPo, 2000 mAh | 1× | Energiespeicher | 51 × 33 × 10 mm |
| TP4057-Lademodul | 1× | Lader + Schutz-IC | Silk „LX-LBES", Pins IN±/BAT±/OUT± |
| LDO-Breakout | 1× | 3,3-V-Versorgung ESP | SOT23-5 „N1F", Silk „V987", 3-Pin Vi/GND/Vo — **Vo = 3,3 V gemessen/bestätigt** |
| Master-Schalter SS-12F15-G070 | 1× | Ein/Aus, gesamtes Gerät | Panel-Mount, für −X-Stirnwand vorgesehen (siehe Gehäuse) |
| ESP8266 D1 mini | 1× | Steuerung | |
| MAX7219-Matrix, 4× | 1 Modul | Anzeige | 32×8 |
| Elko 1000 µF / 10 V | 1× | Matrix-V_CC-Pufferung (Bulk) | Spannungsfestigkeit 10 V gewählt für Reserve über max. 4,2 V LiPo-Spannung |
| 1N5817 | 1× | Rückspeisungsschutz LDO-`Vo` → ESP-`3V3` bei gleichzeitigem USB | bedrahtet, DO-41, 1 A / 20 V, Vf ≈ 0,45 V @ 1 A |
| Keramik-C 100 nF | 2× | 1× Matrix-V_CC-Decoupling, 1× Stabilisierung A0-Spannungsteiler | |
| Widerstand 100 kΩ, 1% | 1× | A0-Spannungsteiler, R1 (Akku `OUT+` → A0) | |
| Widerstand 220 kΩ, 1% | 1× | A0-Spannungsteiler, R2 (A0 → GND) | |
| Status-LEDs 5 mm | 2× | LED-Bucht im Gehäuse | rot + grün (Standardfarben, austauschbar) |
| Vorwiderstand 220–330 Ω | 2× | je 1× pro Status-LED | |
| Gehäuse (3D-Druck) | body + cover + feed_plug | fertig gedruckt, Passung bestätigt (17. August 2026) | siehe `hardware/case/` |
| M2-Schrauben, selbstschneidend | 2× | Schalter-Flansch an −X-Wand | Raster 15 mm, Löcher ø2,2 vorbereitet |

## Werkzeug & Verbrauchsmaterial (für die Montage, nicht Teil der Stückliste)

- Lötkolben + Lötzinn, Entlötlitze/Absaugpumpe für Korrekturen
- Multimeter (Spannung + Durchgangsprüfung — vor jedem Einschalten Pflicht)
- Schrumpfschlauch (mehrere Durchmesser) oder Isolierband für blanke Lötstellen
- Seitenschneider + Abisolierzange
- Kleiner Kreuzschlitz- oder Sechskant-Schraubendreher für die M2-Schalterschrauben
- Etwas dünne Litze (verschiedenfarbig empfohlen: rot/schwarz/gelb) für die kurzen Brücken zwischen den Modulen
- Optional: Heißkleber als Zugentlastung für Kabel an den Modul-Lötpads

## A0-Spannungsteiler — Auslegung

Schaltung: `OUT+` (Akku) → R1 (100 kΩ) → **A0** → R2 (220 kΩ) → GND

Teilerfaktor R2/(R1+R2) = 220/320 = **0,6875**

D1-mini-A0-Limit: ≤ 3,2 V

| Akkuspannung | Spannung an A0 |
|---|---|
| 4,2 V (voll) | 2,89 V |
| 3,7 V (nominal) | 2,54 V |
| 3,0 V (leer) | 2,06 V |

Reserve bei voller Ladung: ~0,3 V unter dem A0-Limit.

Stromverbrauch des Teilers: 4,2 V / 320 kΩ ≈ **13 µA** (vernachlässigbar für die Akkulaufzeit).

## Verdrahtungs-Topologie (Kurzfassung)

1S-LiPo → TP4057 (Lader) → `OUT+`/`OUT−` (SYS-Schiene, ~3,0–4,2 V, geschützt)
→ (a) Matrix-V_CC direkt (+ 1000 µF Elko + 100 nF Keramik-C)
→ (b) LDO (`Vi`) → `Vo` → 1N5817 (Anode am LDO) → ESP `3V3`-Pin
→ Master-Schalter SS-12F15-G070 in der `OUT+`-Leitung (schaltet das gesamte Gerät)
→ A0-Spannungsteiler an `OUT+`/GND, Abgriff an D1-mini-`A0`

Gemeinsame Stern-Masse. SPI unverändert (D7 → DIN, D5 → CLK, D8 → CS). Nicht gleichzeitig USB und Akku speisen lassen — laden über die USB-Buchse des TP4057-Moduls.

Siehe auch `hardware/wiring/wiring-sheet.html` — vollständige Montageanleitung
(Reihenfolge Gehäuse/Löten/Erstinbetriebnahme/Endmontage) inklusive großem
Verkabelungsblatt mit nummerierten Lötschritten (Stand 18. August 2026).

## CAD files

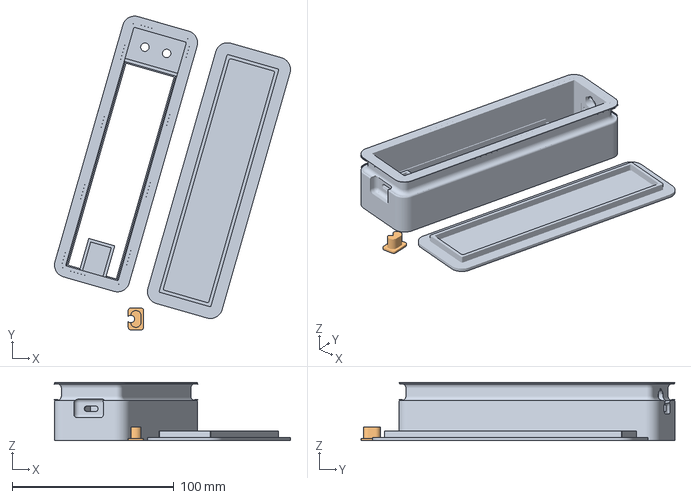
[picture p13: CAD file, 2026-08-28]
hardware/case/case.3mf
146.0 x 194.1 x 36.0 mm
case.stl
feed_plug.stl

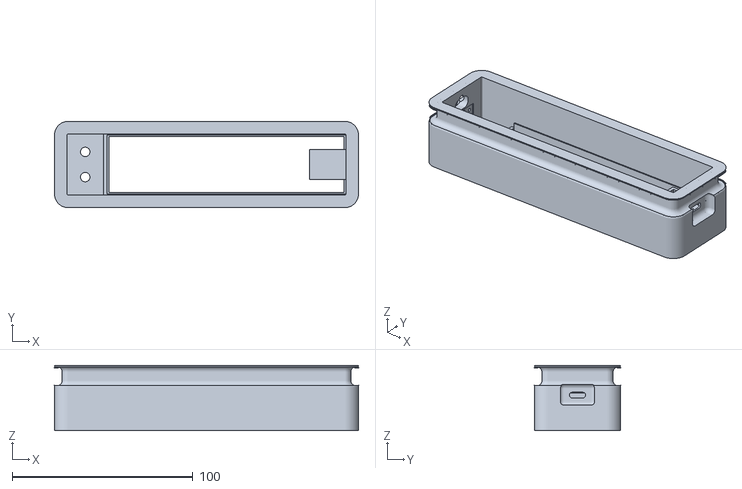
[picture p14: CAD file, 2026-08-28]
hardware/case/stl/body.stl
168.2 x 47.8 x 36.0

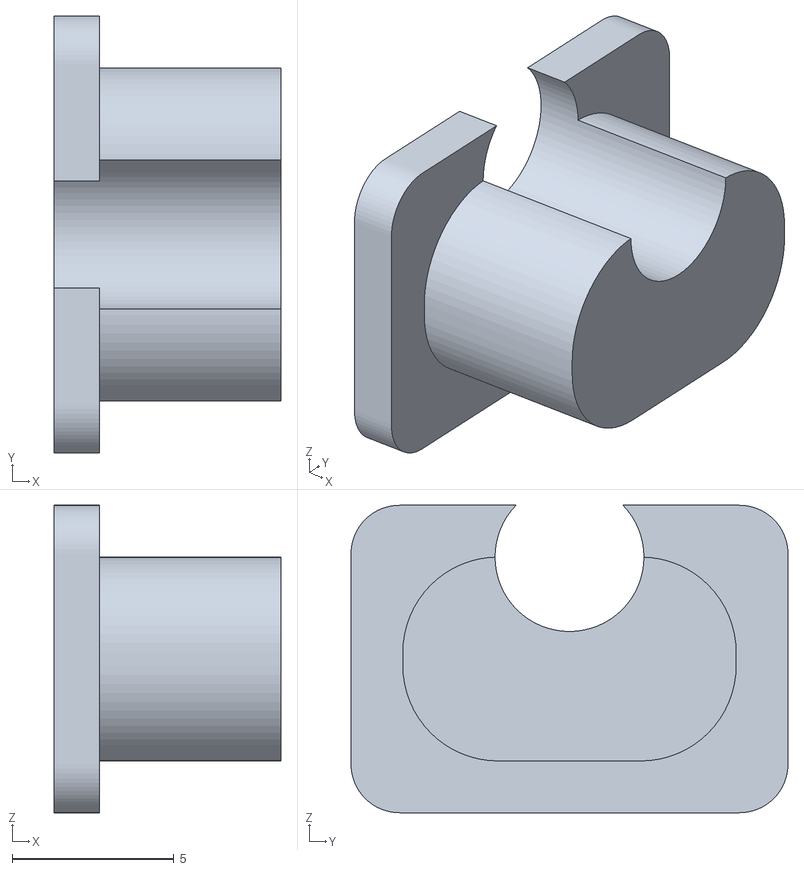
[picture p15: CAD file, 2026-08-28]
hardware/case/stl/feed_plug.stl
7.00 x 13.5 x 9.50

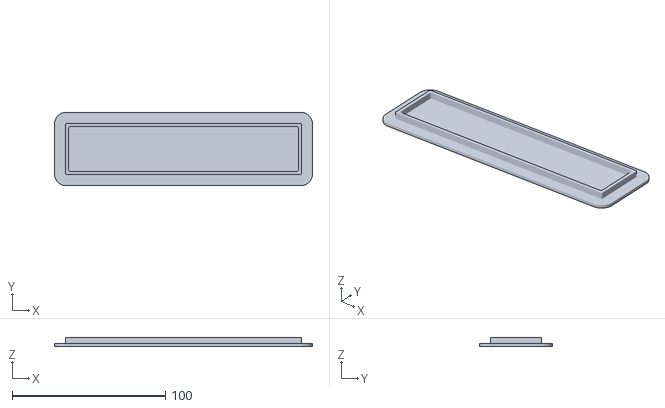
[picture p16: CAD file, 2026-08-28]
hardware/case/stl/cover.stl
168.2 x 47.8 x 5.99

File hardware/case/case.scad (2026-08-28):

// ================================================================
//  Max7219 32x8 Display - Gehaeuse fuer Akkubetrieb
//  Druck: Bambu Lab P1S, PLA.   Einheiten: mm.
//
//  Zwei Teile:
//    body  = Front-Blende + Wanne in einem (Bauteile von HINTEN laden)
//    cover = Rueckdeckel (klippt/reibt ein)
//
//  ---> ALLE mit (*) markierten Masse mit dem Messschieber pruefen
//       und hier oben anpassen. Danach neu rendern.
//  ----------------------------------------------------------------
//  Druck-Orientierung: body mit der FRONT nach UNTEN drucken
//  (Fenster auf dem Druckbett) -> saubere Front, keine Stuetzen.
//  Der Lader-Halter hat eine 45-Grad-Schraege und druckt so mit.
// ================================================================

part = "both";     // [body, cover, both]  -> was gerendert/exportiert wird

$fn = 64;

// ---- Matrix-Modul (FC-16 4-in-1) ------------------------------
disp_w  = 131;   // * Laenge des Moduls (lange Kante)     [gemessen]
disp_h  = 32;    // * Hoehe des Moduls (kurze Kante)      [gemessen]
disp_d  = 14;    // * Tiefe inkl. Rueckseiten-Header      [gemessen]
led_ov  = 0.5;   //   Ueberlappung Blende<->Modul pro Seite. LEDs bis zum Rand,
                 //   daher minimal. Matrix wird durch mfit eng gefuehrt, damit
                 //   der schmale Rand rundum fasst. Halt zusaetzlich uebers
                 //   Sandwich (Deckel druckt Bauteile gegen die Matrix).
                 //   -> beim naechsten Coupon feinjustieren (0.4-0.6).

// ---- LED-Bucht (2x 5mm LED neben der Matrix, -X Seite) --------
// Verbreitert den Innenraum in X: zwischen der linken (-X) Stirnwand und
// der Matrix entsteht eine Bucht. Zwei 5-mm-LEDs sitzen VERTIKAL gestapelt,
// Presssitz durch die Front. Eine duenne Abstandhalter-Rippe (spacer) trennt
// Bucht und Matrix und bildet den -X Endanschlag der Matrix (die vorher
// beidseitig eng gefuehrt war). Rueckraum bleibt frei fuer die LED-Verdrahtung.
led_en    = true;   // LED-Bucht an/aus (aus -> Gehaeuse wie vorher)
led_bay_w = 20;     // * Breite der Bucht in X (innen)
led_spacer = 2.0;   //   Dicke der Abstandhalter-Rippe (Bucht <-> Matrix)
led_spacer_drop = 3; //  Rippe endet X mm vor der Matrix-Rueckseite (Z) -> Spalt
                     //   fuer seitlich abstehende Matrix-Anschluss-Pins
led_d     = 5.2;    // * Loch-Durchmesser fuer 5mm LED (Presssitz; ggf. 5.0-5.4)
led_pitch = 14;     //   Y-Abstand der beiden LED-Mitten (um OY/2 zentriert)

// ---- Rueckraum (Akku / D1 mini / Lader liegen hier) -----------
comp_depth = 20; // * Tiefe hinter der Matrix = dickstes Bauteil + Reserve
                 //   (D1 mini mit Stiftleisten ~12 mm; Akku 10 mm -> 14 = Luft).
                 //   Auf 20 erhoeht, damit die 2 Aufwickel-Windungen sauber in
                 //   den Rueckraum passen (Zb = front+disp_d+comp_depth = 36 mm).

// ---- Akku (Pouch, 2000 mAh, 51 x 33 x 10) ---------------------
batt_w  = 33;    // * Mass laengs Y (=Hoehe 33; bestimmt die Gehaeusehoehe) [gemessen]
batt_t  = 10;    // * Dicke (in Z; nur Reserve-Check)                       [gemessen]
// (Laenge 51 mm laeuft in X mit, unkritisch)

// ---- USB-C Ladeplatine (TP4057) -------------------------------
chg_l   = 17;    // * Mass in X (nacktes PCB; Tiefe D)              [gemessen]
                 //   Achtung: die Tasche muss ~21 mm fuellen (PCB + USB-C-Ueberstand);
                 //   der Ueberstand steckt in chg_extra, nicht in chg_l.
chg_w   = 12;    // * Mass in Y an der Stirnwand (Breite B)         [gemessen]
chg_t   = 1.4;   // * Platinendicke (geschaetzt - ggf. messen)
// USB-C Oeffnung = Stadion-Form (Rechteck mit voll verrundeten Enden).
// Stecker-Metallschale ist ~8,34 x 2,56 mm; diese Werte = Schale + wenig Spiel.
usbc_w  = 9.0;   // * Breite der Oeffnung (Aussenmass Stadion)
usbc_h  = 3.2;   // * Hoehe der Oeffnung  (= Durchmesser der Rundungen)
usbc_zc = 2.4;   // * Mitte der Buchse ueber Taschenboden (chg_z0). 1.7 -> 2.2 -> 2.4:
                 //   1.7->2.2 = Buchse lag ~0.5 mm hoeher als das Loch. 2.2 passte knapp,
                 //   +0.2 mehr Richtung Rueckseite (+Z) fuer etwas Luft. cz waechst mit.
// Feinabstimmung Stecker-Sitz:
usbc_cb_w = 12.0; //   Option 1: Senkung aussen (fuer Stecker-Koerper) Breite
usbc_cb_h = 6.0;  //   Option 1: Senkung Hoehe
usbc_cb_d = 1.0;  //   Option 1: Senkung Tiefe (Restwand = wall - usbc_cb_d - chg_xshift)
chg_xshift = 0.5; //   Option 2: Platine ragt so weit in eine Innenwand-Aussparung

// ---- Test-Coupon ----------------------------------------------
coupon_len = 32;  //   Laenge des +X-Endstuecks fuer den Testdruck

// ---- Schalter SS-12F15-G070 (Schieber in der -X-Stirnwand, geg. Ladeteil) ----
// Geflanschter SPDT-Schieber (Datenblatt G-Switch, Masse aus der Zeichnung).
// Montage: Flansch mit 2 Schraubloechern liegt INNEN an der -X-Wand; der Schieber
// tritt durch einen Schlitz nach aussen (gleitet in Y/senkrecht), Koerper + Pins
// ragen nach innen (+X). Befestigung: 2x M2-Schraube durch den Flansch in die Wand.
// Zone Z~17-23 (hinter Matrix 16, vor Kabel-Feed ~24). (*) = am Teil nachmessen.
switch_enable = true;
sw_plate_l = 19.5;  //   Flansch-Laenge (Ohr-zu-Ohr, Y)
sw_plate_w = 5.6;   //   Flansch-Breite (Z)
sw_plate_t = 0.4;   //   Flansch-Dicke
sw_hole_sp = 15.0;  //   Schraubloch-Abstand Mitte-Mitte (Y)
sw_body_l  = 10.5;  //   Koerper-Laenge (Y)   [Info/Kollision]
sw_body_w  = 4.6;   //   Koerper-Breite (Z)   [Info/Kollision]
sw_body_h  = 5.0;   //   Koerper-Hoehe unter Flansch, ragt nach innen (X) [Info]
sw_act_w   = 3.0;   //   Schieber-Knopf Breite (Z)
sw_act_l   = 4.0;   // * Schieber-Knopf Laenge (Y) -- am Teil pruefen
sw_travel  = 3.0;   //   Schieber-Weg (Y)
sw_act_h   = 7.0;   //   Schieber-Hoehe ueber Flansch (G070) [Info]
sw_fit     = 0.4;   //   Passungsspiel
sw_screw_d = 1.7;   //   Kernloch fuer M2 (selbstschneidend) in die Wand
sw_zc      = 20;    //   Z-Mitte (frei zw. Matrix 16 und Feed ~24)

// ---- Gehaeuse allgemein ---------------------------------------
wall    = 2.4;   // Wandstaerke Body
front   = 2.0;   // Dicke der Front-Blende
covwall = 2.0;   // Dicke Rueckdeckel
fit     = 0.4;   // Passungsspiel (Bauteile allgemein)
mfit    = 0.25;  // Passungsspiel Matrix in Y (eng -> zentriert, damit Rand fasst)
mfit_x  = 0.6;   // Passungsspiel Matrix in X pro Seite (Laenge). Groesser als mfit,
                 //   weil ueber die 131 mm der XY-Schwund + Messtoleranz die enge
                 //   0.25 auffrisst -> Slot war minimal zu kurz. Sandwich haelt trotzdem.
chg_fit = 1.2;   // Passungsspiel Lader-Halter (locker -> Platine faellt leicht rein)
covfit  = 0.25;  // Passungsspiel Deckel-Lippe (P1S: 0.2-0.3)
corner  = 3.0;   // Aussen-Eckenradius

// ---- abgeleitete Masse (nicht anfassen) -----------------------
led_bay = led_en ? led_bay_w  : 0;        // effektive Bucht-Breite
spacer  = led_en ? led_spacer : 0;        // effektive Abstandhalter-Dicke
mat_slot_w = disp_w + 2*mfit_x;           // X-Slot der Matrix (Laenge; etwas lockerer)
inner_w = led_bay + spacer + mat_slot_w;  // X innen (Bucht + Rippe + Matrix)
inner_h = max(disp_h + 2*mfit, batt_w + 2*fit); // Y innen (Akku ODER Matrix)
inner_d = disp_d + comp_depth;            // Z innen (Front->Deckel)

matrix_x0 = wall + led_bay + spacer;      // -X Kante des Matrix-Slots

OX = inner_w + 2*wall;   // Aussen X
OY = inner_h + 2*wall;   // Aussen Y
Zb = front + inner_d;    // Body-Tiefe (bis Deckelkante)

win_w = disp_w - 2*led_ov;   // Fenster
win_h = disp_h - 2*led_ov;
win_x0 = matrix_x0 + mfit_x + led_ov;   // -X Kante Fenster (mit Matrix ausgerichtet)

// Lader-Halter: rechte Stirnwand (+X), Platine in Y zentriert.
// WICHTIG: Alles bleibt HINTER der Matrix (Z > disp_d), damit die Matrix
// mit ihrem rechten Ende noch reinpasst. Abstuetzung: Stirnwand + Fins.
chg_gap  = 1.2;                      // Luft zwischen Matrix-Rueckseite und Platine (Z).
                                     //   Von 2.0 auf 1.2 -> Platine faellt 0.8 mm tiefer.
                                     //   Das ist das MAX: Bodenplatte-Unterkante liegt dann
                                     //   bündig an der Matrix-Rueckseite (Z=16). Nicht weiter.
chg_z0   = front + disp_d + chg_gap; // Platinen-Unterseite (Z)  ~18
chg_y0   = (OY - chg_w)/2;           // Platinen -Y Kante
chg_extra = 2.0;                     // zusaetzliche Tiefe (X) der Ladetasche.
                                     //   sx = chg_l+chg_fit+chg_extra = 17+1.2+2.0 = 20.2 mm.
                                     //   Zurueck auf den Originalwert: die frueheren Symptome
                                     //   ("zu kurz", "1 mm locker") kamen NICHT von der Laenge,
                                     //   sondern von der 0.5 mm zu hohen USB-C-Buchse (siehe
                                     //   usbc_zc). Sitzt die Buchse im Loch, fixiert der Stecker
                                     //   die X-Position -> 3.2 mm Luft in der Tasche sind egal.
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

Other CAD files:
hardware/case/stl/case.3mf

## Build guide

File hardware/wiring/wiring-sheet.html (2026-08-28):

Hardware · Montageanleitung & Verkabelungsblatt

# Pixel Status im Akkubetrieb — Montage

Alle Teile sind vollständig (Stückliste: hardware/wiring/parts-list.md), das Gehäuse (body + cover) ist gedruckt und passt. Diese Seite führt durch die komplette Montage: Gehäuse vorbereiten → löten → auf der Werkbank testen → einbauen → Firmware konfigurieren. Die nummerierten Kreise (①–⑧) in der Löt-Reihenfolge unten entsprechen den Schritten im Verkabelungsblatt.

Leistung (Akku / SYS / 3,3 V) Signal — SPI Masse & Steuerung Löt-/Montageschritt (Reihenfolge)

Ablauf

## Montage in 5 Phasen

Jede Phase ist unten als eigener Abschnitt mit Details ausgeführt — diese Übersicht dient als roter Faden.

Phase A

### Gehäuse vorbereiten

Druckgrat entfernen, Passprobe, Schalter final verschrauben.

Phase B

### Löten (Werkbank)

8 Schritte in fester Reihenfolge, siehe Diagramm.

Phase C

### Bench-Test

Vor dem Einbau offen testen — Fehler jetzt sind leicht zu beheben.

Phase D

### Endmontage

Module ins Gehäuse, Kabel wickeln, Deckel schließen.

Phase E

### Firmware-Konfig

WLAN einrichten, Akkumessung freischalten.

Phase A

## Gehäuse vorbereiten

1. Druckgrat/Stützreste entfernen An body, cover und feed_plug — besonders im Matrix-Slot, der Ladetasche und der Kabel-Nut. Ein Cutter oder feines Schleifpapier reicht.
2. Trockene Passprobe Matrix probeweise in den Slot schieben, Lademodul in die Tasche legen, Deckel auflegen — noch nichts kleben oder verlöten. Bei Klemmen: Stelle mit Schleifpapier nacharbeiten statt zu forcieren (PLA splittert sonst).
3. Master-Schalter final montieren Flansch innen an die −X-Stirnwand, Schieber ragt durch den Schlitz nach außen. Mit 2× M2 selbstschneidenden Schrauben durch die vorbereiteten ø2,2-Löcher (Raster 15 mm) fixieren.

Falls der Schalter laut Stückliste schon montiert ist: Sitz und Schraubenanzug trotzdem kurz prüfen, bevor die Verkabelung an ihm hängt.

Phase B · Kern

## Löt-Reihenfolge & Leistungspfad

Alles in dieser Phase passiert außerhalb des Gehäuses, frei zugänglich auf der Werkbank. Die Matrix hängt direkt an der Akkuschiene (No-Shift, ≤ ~4,5 V), damit die 3,3-V-SPI ohne Pegelwandler funktioniert. Die Kreiszahlen entsprechen der empfohlenen Lötreihenfolge — von innen nach außen ist unkritisch, aber diese Reihenfolge lässt jeden Schritt einzeln mit dem Multimeter prüfen, bevor der nächste dazukommt.

Master aus + USB am D1 mini: Der ESP läuft dann aus USB (für Flashen/Debug), die Matrix bleibt aus — die Schottky (①→②) verhindert, dass USB-Strom in die abgeschaltete SYS-Schiene zurückfließt.

1. LDO verdrahten `Vi` an SYS (kommt später über den Schalter), `GND` an Stern-Masse, `Vo` vorerst offen lassen (folgt in Schritt ②).
2. Schottky 1N5817 einlöten Anode an LDO-`Vo`, Kathode an ESP-`3V3` — Polung unbedingt prüfen, sonst kein Rückspeisungsschutz.
3. A0-Spannungsteiler aufbauen R1 (100 kΩ) von SYS nach A0, R2 (220 kΩ) von A0 nach GND, 100 nF parallel zu R2 (A0–GND) zur Stabilisierung. Am besten frei verdrahtet als kleines Bündel, dann mit Schrumpfschlauch isolieren.
4. Lader anschließen LiPo-Balancerstecker an `BAT±` des TP4057, `OUT±` wird zur SYS-Schiene (Schalter kommt in Schritt ⑥ dazwischen). USB-C-Ladeport bleibt frei zugänglich.
5. Matrix-Stützkondensatoren anlöten 1000 µF Elko + 100 nF Keramik-C direkt an Matrix-`VCC`/`GND`, dann `VCC` an SYS, `GND` an Stern-Masse.
6. Schalter einschleifen In die `OUT+`-Leitung zwischen Lader und SYS-Schiene — COM + ein Außenpin als einfacher Ein/Aus. Nicht zwischen Zelle und Lader schalten, sonst funktioniert Laden/Schutz im Aus-Zustand nicht.
7. Stern-Masse zusammenführen LiPo−/Lader-GND, Matrix-GND, LDO-GND und ESP-GND an einem gemeinsamen Punkt verlöten (z. B. kurzer Massedraht als „Sammelschiene").
8. SPI verdrahten D7→DIN, D5→CLK, D8→CS, kurze Drähte direkt zwischen D1 mini und dem 5-poligen Matrix-Eingang.

Status-LEDs (Schritt „⑨", siehe unten) und die finale Verkabelung ins Gehäuse folgen erst in Phase D — bis dahin bleibt alles frei zugänglich für Multimeter-Checks.

Signal

## ESP ↔ Matrix — Hardware-SPI (Schritt ⑧)

Ein 5-poliger Eingang der 4-in-1-Platine; die vier MAX7219 sind onboard durchgekettet.

Signal | D1-mini-Pin | GPIO | Hinweis
DIN | D7 | GPIO13 | HW-SPI MOSI — fest
CLK | D5 | GPIO14 | HW-SPI SCK — fest
CS | D8 | GPIO15 | CS_PIN — frei wählbar
VCC | SYS | — | an der Akkuschiene, nicht an 5 V
GND | ⏚ | — | Stern-Masse · 1000 µF + 100 nF an VCC/GND

Anzeige

## Status-LEDs (Schritt ⑨)

Active-High (LED_ACTIVE_LOW=false): GPIO → Vorwiderstand → Anode, Kathode → GND. In die LED-Bucht im Gehäuse gepresst (ø5,2 mm Fenster).

LED | Pin | GPIO | R
1 · rot | D2 | GPIO4 | 220–330 Ω
2 · grün | D1 | GPIO5 | 220–330 Ω

Beide GPIOs sind boot-neutral. Countdown-Warnung lässt beide blinken. Kabel lang genug lassen, damit die LEDs später von hinten in die Front-Löcher gedrückt werden können.

Schalter

## Master-Schalter direkt (Schritt ⑥)

SS-12F15 laut Datenblatt 1,0 A / 24 V DC. Reale Last: typ. ~0,15–0,3 A, Worst Case (Vollweiß + max. Helligkeit) ~0,8–1 A — passt, kein MOSFET nötig.

- Schalter in die OUT+-Leitung (geschützter Ausgang) → schaltet das ganze Gerät
- COM + ein Außenpin nutzen (SPDT als einfacher Ein/Aus)
- Laden über den Lader-USB läuft auch im Aus-Zustand
- Aus = nur noch ~µA Ruhestrom von Lader-/Schutz-IC

Absicherung

## Schutz gegen doppelten USB-Anschluss (Schritte ①–②)

Konflikt entsteht nur auf der 3,3-V-Schiene: Lader-USB (Akku) plus D1-mini-USB würden zwei Regler gegeneinander treiben. Eine Schottky in der Einspeisung trennt sie.

- Schottky: 1N5817 (bedrahtet, DO-41, 1 A/20 V, Vf ≈ 0,45 V @1A): Anode → LDO Vo, Kathode → ESP 3V3
- Blockiert Rückfluss ESP→LDO — die Regler treiben sich nie gegenseitig
- Drop ~0,25–0,3 V bei den hier üblichen ~100–300 mA → ESP bei ~3,0–3,05 V (läuft; Reserve im Blick behalten)
- Bei WLAN-Instabilität: MOSFET-„Ideal-Diode" statt Schottky (kein Drop)

Messung

## A0-Spannungsteiler — Akku-%-Anzeige (Schritt ③)

Skaliert die SYS-Schiene (3,0–4,2 V) auf das D1-mini-A0-Limit (≤ 3,2 V) herunter, Basis für die „LOW BATT"-Anzeige in /api/health — siehe Diagramm oben.

- R1 = 100 kΩ (1%): SYS/OUT+ → A0
- R2 = 220 kΩ (1%): A0 → GND
- Teilerfaktor 220/320 = 0,6875 → 4,2 V→2,89 V · 3,7 V→2,54 V · 3,0 V→2,06 V
- 100 nF zwischen A0 und GND — stabilisiert die Messung am hochohmigen Teiler (320 kΩ)
- Ruhestrom: 4,2 V / 320 kΩ ≈ 13 µA — für die Laufzeit vernachlässigbar

Nach dem Verlöten nicht vergessen: BATTERY_MONITOR_ENABLED in include/config.h von false auf true setzen und neu flashen — sonst bleibt die Akkuanzeige in /api/health deaktiviert (Standard, solange der Teiler unverlötet war).

Phase C

## Bench-Test — vor dem Einbau, außerhalb des Gehäuses

Fehler jetzt zu finden ist einfach (alles liegt offen und ist mit dem Multimeter erreichbar); im geschlossenen Gehäuse wird jede Korrektur mühsam. Diese Checkliste vor dem ersten Einschalten abarbeiten:

1. LDO-Ausgang = 3,3 V ✓ gemessen/bestätigt (17. August 2026) — kein Buck-Boost nötig.
2. Matrix-VCC an SYS Niemals an einen 5-V-Pin des D1 mini.
3. Schottky-Polung (1N5817) Anode am LDO, Kathode am ESP — sonst kein Schutz.
4. Schalter in OUT+ In die geschützte OUT+-Leitung — nicht zwischen Zelle und Modul (sonst kein Laden/Schutz im Aus-Zustand).
5. Stern-Masse LiPo−, Matrix-GND, LDO-GND und ESP-GND auf einen gemeinsamen Punkt — mit dem Multimeter im Durchgangsmodus zwischen allen vier Punkten prüfen.
6. Stützkondensatoren 1000 µF + 100 nF direkt an Matrix-VCC/GND, 100 nF an A0/GND.
7. Kein Kurzschluss Vor dem ersten Akku-Anschluss: Widerstand zwischen SYS+ und GND messen (sollte hochohmig sein, nicht 0 Ω).
8. Erststart nur über USB LiPo noch nicht anschließen. D1 mini per USB flashen/testen, Matrix soll das gewohnte Boot-Verhalten zeigen.
9. Dann Akku statt USB USB trennen, LiPo anschließen, Schalter auf Ein — Matrix muss leuchten. Falls nicht: sofort trennen, nicht weitersuchen unter Spannung.
10. LEDs einzeln testen Über die Web-UI oder led 1 on / led 2 on per USB-Seriell — beide Farben, beide Blinkmuster.

Phase D

## Endmontage ins Gehäuse

1. Nochmals auf Kurzschluss/Wackelkontakt prüfen Bevor irgendetwas fest im Gehäuse verschwindet.
2. Matrix von hinten in den Slot schieben Bis zum Anschlag an der Lader-seitigen Wand; sitzt im Sandwich zwischen Front und Deckel, kein Kleben nötig.
3. LEDs in die Front-Löcher drücken Von hinten durch die LED-Bucht, Presssitz.
4. Lademodul in die Tasche legen USB-C-Buchse sitzt in der Stirnwand-Öffnung; Platine wird über die verlöteten Kabel gehalten (kein zusätzliches Kleben).
5. D1 mini + restliche Elektronik (LDO, Schottky, A0-Teiler) im Rückraum platzieren Lose Enden mit Schrumpfschlauch isolieren, damit nichts im Gehäuse Kontakt bekommt.
6. LiPo-Akku einlegen Flach im Rückraum, Kabel zum Lader kurz genug für Zugentlastung.
7. Steuerkabel durch die Durchführung fädeln Micro-USB-Stecker durch die große Öffnung, Kabel in den Klemmschlitz drücken, restliche Länge in der umlaufenden Nut aufwickeln (2 Windungen bei 70 cm Kabel).
8. Verschluss-Stopfen einsetzen (feed_plug) verschließt die Durchführungsöffnung im Presssitz.
9. Deckel aufsetzen Reib-/Klipplippe, gleichmäßig andrücken.
10. Funktionstest im geschlossenen Gehäuse Schalter Ein, Matrix + beide LEDs prüfen, Schalter Aus, danach laden testen (USB-C am Lader, Gerät bleibt aus).

Phase E

## Firmware-Erstkonfiguration

1. WLAN einrichten Kein bekanntes Netz beim ersten Boot → Gerät öffnet den Setup-Hotspot; unter http://192.168.4.1/wifi Zugangsdaten eintragen.
2. Erreichbarkeit prüfen Danach über http://pixelstatus.local (Hostname im System-Tab änderbar) oder die vergebene IP.
3. Akkuanzeige freischalten BATTERY_MONITOR_ENABLED true in include/config.h, neu flashen, auf /health Spannung/Prozent gegen ein Multimeter gegenchecken.
4. Optional: MQTT/Companion-App Nach Bedarf über /settings bzw. die Companion-App unter Windows/macOS einrichten.

Pins: include/config.h · Topologie: No-Shift 1S-LiPo

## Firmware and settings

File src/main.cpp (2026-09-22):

#include <Arduino.h>
#include <ESP8266WiFi.h>
#include <ESP8266mDNS.h>

#include "config.h"
#include "DisplayManager.h"
#include "Leds.h"
#include "Battery.h"
#include "NetManager.h"
#include "TimeManager.h"
#include "WebPortal.h"
#include "MqttBridge.h"
#include "SerialBridge.h"
#include "LoopStats.h"

DisplayManager display(CS_PIN, MAX_DEVICES);
LedController  leds(LED_PIN_1, LED_PIN_2, LED_ACTIVE_LOW, LED_WARN_SECS, LED_WARN_FAST_SECS);
BatteryMonitor battery(A0, BATTERY_MONITOR_ENABLED, BATTERY_EMPTY_V, BATTERY_FULL_V,
                       BATTERY_LOW_PERCENT, BATTERY_LOW_BRIGHTNESS);
NetManager     net;
TimeManager    timeMgr;
MqttBridge     mqtt(display, leds, battery);
WebPortal      web(display, net, mqtt, leds, timeMgr, battery);
SerialBridge   serialCtl(display, leds, web);

// Haelt die Scroll-Animation waehrend der (blockierenden) WiFi-Wartezeit am Laufen
// und treibt bei BOOT_PROGRESS zusaetzlich den an den echten Connect gekoppelten
// Fortschrittsbalken an (siehe DisplayManager::bootProgressUpdate()).
static const uint32_t WIFI_CONNECT_TIMEOUT_MS = 20000;
static unsigned long  s_connectStart = 0;
static void pumpDisplay() {
  display.loop();
  if (display.bootAnimation() == DisplayManager::BOOT_PROGRESS) {
    float frac = (float)(millis() - s_connectStart) / (float)WIFI_CONNECT_TIMEOUT_MS;
    display.bootProgressUpdate(frac > 1.0f ? 1.0f : frac);
  }
}

// Waehrend der Setup-Hotspot offen ist (kein WLAN konfiguriert/erreichbar,
// siehe NetManager::startAP()), wechselt die Matrix im Sekundentakt zwischen
// AP-Name und -Passwort, damit man das (geraetespezifisch generierte, siehe
// SEC-05) Passwort ablesen kann, ohne die Weboberflaeche zu brauchen. Endet,
// sobald sich ein Geraet mit dem Hotspot verbindet -- ab dann ist vermutlich
// schon jemand am Smartphone/Laptop im Einrichtungsdialog -- ODER sobald ein
// Befehl ueber USB eingeht: dann steuert jemand das Geraet per Kabel und
// braucht die Hotspot-Zugangsdaten gar nicht, waehrend die Anzeige alle paar
// Sekunden jeden per USB gesetzten Inhalt ueberschreiben wuerde.
static bool          s_apSetupDone    = false;
static bool          s_apTimerStarted = false;
static bool          s_apShowingPass  = false;
static unsigned long s_apLastSwitch   = 0;
static void handleApSetupDisplay() {
  if (!net.apActive() || s_apSetupDone) return;
  if (WiFi.softAPgetStationNum() > 0) {
    // Jemand hat sich verbunden -> Anzeige aktiv beenden statt SSID/Passwort
    // einfach stehen zu lassen. clearBrightnessOverride() nur zur Sicherheit,
    // falls die Akku-Warnung (siehe handleBatteryWarning()) waehrend der
    // Wartezeit doch schon einmal gedimmt hatte.
    s_apSetupDone = true;
    display.clear();
    display.clearBrightnessOverride();
    return;
  }
  if (serialCtl.commandSeen()) {
    s_apSetupDone = true;
    // Nur loeschen, wenn tatsaechlich noch SSID/Passwort auf der Matrix steht:
    // ein Steuerbefehl (text/preset/clock/timer) hat die Anzeige schon selbst
    // uebernommen und soll sie behalten, ein reiner Abfragebefehl (get*/cfg*)
    // hat sie unberuehrt gelassen und wuerde die Zugangsdaten stehen lassen.
    if (display.showsScrollText(net.apSsid()) || display.showsScrollText(net.apPassword()))
      display.clear();
    // Wie im Zweig oben nur zur Sicherheit -- handleBatteryWarning() haelt sich
    // waehrend des AP-Setups zurueck und bewertet den Akkustand ab jetzt wieder
    // regulaer (dimmt also ggf. im naechsten loop() erneut).
    display.clearBrightnessOverride();
    return;
  }
  if (!s_apTimerStarted) {
    s_apTimerStarted = true;
    s_apLastSwitch = millis();
    // Passwort muss lesbar sein, auch wenn schon vor dem Setup-Hotspot eine
    // Akku-Dimmung aktiv war -- handleBatteryWarning() haelt sich waehrenddessen
    // ohnehin zurueck (siehe dort), das hier faengt nur den Fall ab, dass die
    // Dimmung schon VOR startAP() gesetzt wurde.
    display.clearBrightnessOverride();
    return;
  }
  if (millis() - s_apLastSwitch < 6000) return;   // ca. eine volle Scroll-Runde je Text
  s_apLastSwitch = millis();
  s_apShowingPass = !s_apShowingPass;
  display.scrollMessage(s_apShowingPass ? net.apPassword() : net.apSsid());
}

// Einmaliger Uebergang bei Unter-/Ueberschreiten der Low-Battery-Schwelle:
// Anzeige "LOW BATT" nur beim Eintritt (kein Neustart der Scroll-Animation in
// jedem loop()), Helligkeit bleibt gedrosselt, bis der Zustand wieder verlaesst.
static bool s_batteryWasLow = false;
static void handleBatteryWarning() {
  if (!battery.enabled()) return;
  // Solange der Setup-Hotspot noch SSID/Passwort anzeigt, hat das Vorrang:
  // "LOW BATT" wuerde die Anzeige ueberschreiben, die Dimmung sie unlesbar
  // machen (am Geraet beobachtet -- Passwort nach ein paar Durchlaeufen
  // nicht mehr lesbar). low bleibt dabei unausgewertet -> keine verlorene
  // Zustandsaenderung, s_batteryWasLow wird beim naechsten regulaeren Aufruf
  // (AP-Setup beendet) ganz normal gegen den dann aktuellen Wert geprueft.
  if (net.apActive() && !s_apSetupDone) return;
  bool low = battery.low();
  if (low && !s_batteryWasLow) {
    display.scrollMessage("LOW BATT");
    display.setBrightnessOverride(battery.lowBrightness());
  } else if (!low && s_batteryWasLow) {
    display.clearBrightnessOverride();
  }
  s_batteryWasLow = low;
}

// Koppelt das Bomben-Gimmick des Spiels an die beiden Zusatz-LEDs, ohne dass
// DisplayManager LedController kennen muesste (dieselbe Entkopplung wie bei
// der Countdown-Warnung oben). Waehrend eines Spiels zeigen beide LEDs per
// Ein/Aus, ob ihre Bombe noch verfuegbar ist (An = verfuegbar, startet mit
// Spielbeginn; Blinken = wird gerade gezuendet; Aus = verbraucht). Verlaesst
// das Spiel GAME (Game Over ODER "Aus"), schaltet gameLedState() beide LEDs
// explizit aus, statt sie im letzten Bomben-Zustand haengen zu lassen. Nur
// bei tatsaechlichem Wechsel anwenden (Flankenerkennung je LED) --
// LedController::set() setzt bei jedem Aufruf mit s != BLINK auch das
// globale Wechselblinken zurueck, staendiges Aufrufen wuerde das kaputt machen.
static DisplayManager::GameLedState s_gameLed[2] = {
  DisplayManager::GLED_NONE, DisplayManager::GLED_NONE
};
static void handleGameBombLed() {
  for (uint8_t i = 0; i < 2; i++) {
    DisplayManager::GameLedState st = display.gameLedState(i);
    if (st == s_gameLed[i]) continue;
    s_gameLed[i] = st;
    switch (st) {
      case DisplayManager::GLED_AVAILABLE: leds.set(i, LedController::ON);    break;
      case DisplayManager::GLED_FLASH:     leds.set(i, LedController::BLINK); break;
      case DisplayManager::GLED_USED:      leds.set(i, LedController::OFF);  break;
      case DisplayManager::GLED_NONE:      break;   // noch nie gespielt -> LED unangetastet lassen
    }
  }
}

void setup() {
  Serial.begin(115200);
  display.begin(DEFAULT_BRIGHTNESS);
  leds.begin();
  battery.begin();
  net.begin();
  timeMgr.begin();   // Zeitzone setzen + NTP gemaess gespeicherter Konfig starten/stoppen

  // Einschalt-Animation fuellt die dunkle Luecke bis hierhin. BOOT_PROGRESS
  // ist ein Sonderfall: er laeuft nicht vorab fix-dauernd, sondern waehrend
  // der eigentlichen WiFi-Wartezeit unten (angetrieben von pumpDisplay()) --
  // und ersetzt dafuer den "WiFi..."-Text, statt gleichzeitig mit ihm um
  // denselben Pixelpuffer zu konkurrieren. Alle anderen Typen laufen VOR dem
  // WiFi-Versuch: startBootAnimation() ist nicht-blockierend (loop() treibt
  // sie ueber stepBootAnimation() an), das kleine Wartschleifchen hier ist an
  // dieser Stelle unproblematisch, da web/mqtt/seriell noch gar nicht laufen.
  uint8_t bootAnim = display.bootAnimation();
  bool showConnectingText = true;
  if (bootAnim == DisplayManager::BOOT_PROGRESS) {
    display.bootProgressBegin();
    showConnectingText = false;
  } else if (bootAnim != DisplayManager::BOOT_OFF) {
    display.startBootAnimation(bootAnim);
    while (display.animationActive()) { display.loop(); delay(5); }
  }

  if (showConnectingText) display.scrollMessage("WiFi...");
  s_connectStart = millis();
  if (net.connectSTA(WIFI_CONNECT_TIMEOUT_MS, pumpDisplay)) {
    MDNS.begin(net.hostname().c_str());
    MDNS.addService("http", "tcp", 80);
    Serial.printf("\nBereit: http://%s.local  (%s)\n",
                  net.hostname().c_str(), WiFi.localIP().toString().c_str());
    display.scrollMessage(WiFi.localIP().toString());
  } else {
    // Kein WiFi -> Setup-Hotspot oeffnen (Steuerung + WiFi-Einrichtung unter 192.168.4.1).
    net.startAP();
    Serial.printf("\nKein WiFi - Setup-Hotspot '%s' offen (http://192.168.4.1/wifi)\n",
                  net.apSsid().c_str());
    display.scrollMessage(net.apSsid());
  }

  web.begin();
  serialCtl.begin();
  mqtt.begin();   // verbindet nur, wenn zur Laufzeit aktiviert (siehe /mqtt)
}

void loop() {
  LoopStats::tick();
  display.loop();
  leds.updateCountdown(display.timerRemaining());   // Countdown-Warnung der Zusatz-LEDs
  handleGameBombLed();
  leds.loop();
  battery.loop();
  handleBatteryWarning();
  handleApSetupDisplay();
  web.loop();
  serialCtl.loop();
  MDNS.update();
  mqtt.loop();
  timeMgr.loop();   // NTP nach WiFi-(Re-)Connect neu synchronisieren
}

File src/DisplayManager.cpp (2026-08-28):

#include "DisplayManager.h"
#include <time.h>
#include <LittleFS.h>
#include <string.h>

// Gespeicherte Helligkeit (ueberlebt Neustarts).
static const char* BRIGHT_PATH = "/bright.txt";
static uint8_t loadBrightness(uint8_t def) {
  File f = LittleFS.open(BRIGHT_PATH, "r");
  if (!f) return def;
  long v = f.parseInt();
  f.close();
  return (v >= 0 && v <= 15) ? (uint8_t)v : def;
}

// Gespeicherte Ausrichtung (ueberlebt Neustarts).
static const char* ORIENT_PATH = "/orient.txt";
static uint16_t loadOrientation() {
  File f = LittleFS.open(ORIENT_PATH, "r");
  if (!f) return 0;
  long v = f.parseInt();
  f.close();
  return (v == 180) ? (uint16_t)v : 0;
}

// Gespeicherte Scrollrichtung (ueberlebt Neustarts).
static const char* SCROLLDIR_PATH = "/scrolldir.txt";
static bool loadScrollReverse() {
  File f = LittleFS.open(SCROLLDIR_PATH, "r");
  if (!f) return false;
  long v = f.parseInt();
  f.close();
  return v == 1;
}

// Gespeicherter Top-Score des Space-Invaders-Gimmicks (ueberlebt Neustarts,
// siehe gameOverEnd()).
static const char* TOPSCORE_PATH = "/topscore.txt";
static uint16_t loadTopScore() {
  File f = LittleFS.open(TOPSCORE_PATH, "r");
  if (!f) return 0;
  long v = f.parseInt();
  f.close();
  return (v >= 0 && v <= 65535) ? (uint16_t)v : 0;
}

// Kehrt die Bitreihenfolge eines Bytes um (Bit 0 <-> Bit 7 usw.) -- fuer die
// 90/180-Grad-Rotation (siehe renderRotated()).
static uint8_t reverseBits8(uint8_t v) {
  v = (uint8_t)((v & 0xF0) >> 4 | (v & 0x0F) << 4);
  v = (uint8_t)((v & 0xCC) >> 2 | (v & 0x33) << 2);
  v = (uint8_t)((v & 0xAA) >> 1 | (v & 0x55) << 1);
  return v;
}

// Gespeicherte Einschalt-Animation (ueberlebt Neustarts).
static const char* BOOTANIM_PATH = "/bootanim.txt";
static uint8_t loadBootAnim() {
  File f = LittleFS.open(BOOTANIM_PATH, "r");
  if (!f) return DisplayManager::BOOT_SCAN;   // Default fuer neue/aktualisierte Geraete
  long v = f.parseInt();
  f.close();
  return (v >= 0 && v <= 3) ? (uint8_t)v : DisplayManager::BOOT_SCAN;
}

// FC16_HW passt zu den verbreiteten 4-in-1 MAX7219-Modulen. Falls die Anzeige
// gespiegelt/verschoben erscheint, hier auf GENERIC_HW oder PAROLA_HW wechseln.
#define HARDWARE_TYPE MD_MAX72XX::FC16_HW

// Die eingebaute Systemschrift laesst Zeile 7 (unterste Reihe) bei den meisten
// Zeichen frei (Buchstaben/Ziffern nutzen nur Zeile 0-6) -- Text "schwebt" dadurch
// eine Zeile ueber der unteren Kante statt auf ihr zu sitzen. Fix: einmalig beim
// Start eine Kopie der Schrift bauen, in der jedes Zeichen um 1 Zeile nach unten
// verschoben ist (Byte << 1, da Bit r = Zeile r). Zeichen mit Unterlaenge (g, j,
// p, q, y, ...) nutzen Zeile 7 bereits selbst -> die bleiben unverschoben, sonst
// wuerde ihr unterster Pixel abgeschnitten. Deckt den druckbaren ASCII-Bereich
// sowie Latin-1 (32-252, inkl. Ä/Ö/Ü/ß/ä/ö/ü) ab -- der Bereich MUSS laut
// MD_MAX72xx-Fontformat luecken-frei sein (first..last durchlaufend), daher auch
// die dazwischenliegenden, selten genutzten Codes; setFont() nimmt laut
// Bibliothek auch einen RAM-Zeiger (kein AVR-PROGMEM-Zwang auf dem ESP8266).
static uint8_t s_shiftedFont[1300];
static void buildShiftedFont(MD_MAX72XX* g) {
  const uint8_t first = 32, last = 252;
  uint16_t off = 0;
  s_shiftedFont[off++] = 'F';
  s_shiftedFont[off++] = 2;
  s_shiftedFont[off++] = 0; s_shiftedFont[off++] = first;
  s_shiftedFont[off++] = 0; s_shiftedFont[off++] = last;
  s_shiftedFont[off++] = 8;   // Zeichenhoehe
  for (int code = first; code <= last; code++) {
    uint8_t buf[16];
    uint8_t w = g->getChar((uint8_t)code, sizeof(buf), buf);
    if ((size_t)(off + w + 1) >= sizeof(s_shiftedFont)) break;   // Sicherheitsnetz
    bool hasDescender = false;
    for (uint8_t i = 0; i < w; i++) if (buf[i] & 0x80) { hasDescender = true; break; }
    uint8_t shift = hasDescender ? 0 : 1;
    s_shiftedFont[off++] = w;
    for (uint8_t i = 0; i < w; i++) s_shiftedFont[off++] = (uint8_t)(buf[i] << shift);
  }
}

// Web-UI/MQTT/USB liefern Text als UTF-8 (Browser/Rust-Strings); der Font
// indiziert Umlaute (Ä/Ö/Ü/ß/ä/ö/ü) aber als Einzelbyte-Codes nach Latin-1
// (siehe MD_MAX72xx_font.cpp, "USE_NEW_FONT"-Tabelle, Codes 196-252). Wandelt
// die zweibytigen UTF-8-Folgen der Latin-1-Zusatzzeichen (U+0080-U+00FF, Leitbyte
// 0xC2/0xC3) in das erwartete Einzelbyte um. Andere Mehrbyte-UTF-8-Folgen (Emoji,
// nicht-lateinische Schrift) hat der Font ohnehin nicht -> werden verworfen statt
// als Muell-Bytes gerendert.
static String utf8ToLatin1(const String& in) {
  String out; out.reserve(in.length());
  for (size_t i = 0; i < in.length(); i++) {
    uint8_t c = (uint8_t)in[i];
    if (c < 0x80) {
      out += (char)c;
    } else if ((c == 0xC2 || c == 0xC3) && i + 1 < in.length()) {
      uint8_t c2 = (uint8_t)in[i + 1];
      out += (char)(((c & 0x1F) << 6) | (c2 & 0x3F));
      i++;
    }
  }
  return out;
}

DisplayManager::DisplayManager(uint8_t csPin, uint8_t numDevices)
  : _p(HARDWARE_TYPE, csPin, numDevices), _numDevices(numDevices) {}

void DisplayManager::begin(uint8_t brightness) {
  _p.begin();
  LittleFS.begin();                            // idempotent; fuer gespeicherte Helligkeit/Ausrichtung
  _brightness = loadBrightness(brightness);     // gespeicherter Wert, sonst Default
  _p.setIntensity(_brightness);
  _orientation = loadOrientation();
  _scrollReverse = loadScrollReverse();
  _bootAnim = loadBootAnim();
  _gTopScore = loadTopScore();
  buildShiftedFont(_p.getGraphicObject());       // muss vor dem ersten getChar()-Aufruf stehen
  _p.setFont(s_shiftedFont);                     // gilt fuer Parola UND den eigenen Renderer (buildRotBuf nutzt dieselbe getChar()-API)
  _p.displayClear();
}

void DisplayManager::loop() {
  if (_animActive) {
    // Boot-Animationen schreiben direkt in denselben Puffer, den Parola/
    // renderRotated() verwalten -- wuerden sich also gegenseitig ueberschreiben,
    // liefen beide im selben Tick. Deshalb pausiert die normale Wiedergabe,
    // bis die Animation fertig ist.
    stepBootAnimation();
    return;
  }
  if (_mode == GAME) {
    // Schreibt wie die Boot-Animationen direkt per writeLogicalColumn() --
    // wuerde sich mit Parolas displayAnimate()/renderRotated() genauso ins
    // Gehege kommen, deshalb hier ebenfalls ein fruehes return.
    renderGame();
    return;
  }
  if (_mode == TIMER) renderTimer();
  else if (_mode == CLOCK) renderClock();

  if (_orientation == 0) {
    // IDLE hat nichts zu animieren -- ohne diese Bedingung wuerde
    // displayAnimate() nach clear() (z.B. "Aus") die zuvor konfigurierte
    // Scroll-Animation (etwa den laufenden GAME-OVER-Text) einfach weiter
    // abspielen und den gerade geleerten Puffer wieder ueberschreiben, da
    // displayClear() nur den Pixelpuffer leert, nicht Parolas laufende
    // Animation stoppt.
    if (_mode != IDLE && _p.displayAnimate()) {
      if (_mode == TEXT_SCROLL) _p.displayReset();  // Scrolltext endlos wiederholen
    }
  } else {
    renderRotated();
  }
}
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

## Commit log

2026-08-28 Pixel Status: ESP8266-Firmware für 32×8-LED-Matrix (MAX7219) + Companion-App
    Zeigt vordefinierte Stati (On Air, In a Call, ...), freien Lauftext, Timer
    oder Uhrzeit auf einer 32×8-LED-Matrix aus vier MAX7219-Modulen an einem
    ESP8266. Steuerung gleichwertig über Web-UI, MQTT (inkl. Home-Assistant-
    Discovery) und USB-Seriell. Dazu eine Tray-Companion-App für Windows/macOS
    (Tauri) zur Fernsteuerung per HTTP oder USB.
    [body.stl, case.3mf, case.scad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]
2026-09-22 AP-Setup-Anzeige beim ersten USB-Befehl beenden
    Der Setup-Hotspot zeigte SSID und Passwort im 6-Sekunden-Wechsel endlos
    weiter, auch wenn das Geraet gar nicht ueber WLAN, sondern ueber USB
    gesteuert wurde -- jeder per Kabel gesetzte Inhalt wurde dadurch nach
    kurzer Zeit wieder ueberschrieben.
    SerialBridge merkt sich jetzt, dass ueberhaupt ein Befehl ueber USB
    eingegangen ist (commandSeen(), auch reine get*-Abfragen zaehlen: ein
    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
2026-09-22 Zeitzone zur Laufzeit konfigurierbar
    Uebertragen wird ueber alle drei Wege (Web/MQTT/USB) immer nur ein
    UTC-Zeitstempel; die Umrechnung in Lokalzeit machte die Firmware bisher
    fest gegen das einkompilierte NTP_TZ. Wer die Uhr aus einem Browser in
    einer anderen Zone stellte, bekam auf der Matrix deshalb weiterhin
    deutsche Zeit -- dasselbe galt fuer NTP unabhaengig vom Standort.
    TimeManager haelt die Zone jetzt wie Server und An/Aus in LittleFS
    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
2026-09-22 Doku: Zeitzone, AP-Anzeige und Einordnung der Linux-Abhaengigkeiten
    CLAUDE.md zu TimeManager, System-Tab und AP-Setup-Anzeige nachgezogen.
    companion/README.md haelt fest, warum eine Dependabot-Meldung zu gtk,
    glib oder webkit2gtk keinen ausgelieferten Build betrifft (die App wird
    nur fuer Windows und macOS gebaut, diese Crates kompilieren nur fuer
    Linux-Ziele) und warum sie sich nicht durch ein Update aufloesen laesst
    (Tauri 2.x haengt ueber tao/muda/tray-icon fest an gtk 0.18). Inklusive
    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
2026-09-22 Firmware im arm64-Linux-Container bauen
    Die Xtensa-Toolchain gibt es fuer macOS nur als x86-Binary: weder der
    ESP8266-Arduino-Boardindex noch die PlatformIO-Registry fuehren einen
    arm64-Build, und esp-quick-toolchain hat seit Anfang 2023 kein Release
    mehr. Auf Apple Silicon lief das ueber Rosetta -- faellt das weg, gibt es
    auf dem Mac selbst keinen Weg mehr zu bauen. Fuer Linux existiert die
    Toolchain als aarch64-Build, in einem arm64-Linux-Container laeuft sie
    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
2026-09-22 Dependabot: nicht aufloesbare glib-Meldung ausnehmen
    Dependabot versuchte alle paar Tage ein Sicherheitsupdate fuer glib und
    scheiterte jedes Mal mit security_update_not_possible: der Fix fuer
    GHSA-wrw7-89jp-8q8g steckt erst in 0.20, einen gepatchten 0.18er-Zweig
    gibt es nicht, und alle aktuellen Crates der Tauri-Kette (tao 0.37,
    muda 0.20, wry 0.57, libappindicator 0.9) fordern weiterhin gtk ^0.18.
    glib kommt ausserdem nur ueber Tauris Linux-Kette herein und wird nur
    fuer Linux-Ziele kompiliert -- gebaut und ausgeliefert wird die App nur
    fuer Windows und macOS.
    open-pull-requests-limit: 0 haelt die regulaeren Versionsupdates aus,
    die es bisher auch nicht gab; Sicherheitsupdates bleiben ak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
2026-09-27 Companion-App: Teams-Präsenz als automatische Statusquelle
    Zusätzlich zur Mikrofon-Erkennung kann die automatische Statusquelle auf
    Microsoft Teams gestellt werden: die App liest die Graph-Präsenz
    (GET /me/presence) und mappt InACall/InAMeeting auf "In a Call",
    Busy/DoNotDisturb auf "Busy", BeRightBack auf "BRB" und Available auf
    "On Air". Die Quelle wird in settings.auto_source gewählt
    (off/microphone/teams); das alte auto_call-Feld bleibt für Altbestände
    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
2026-09-27 Teams-Präsenz und neue Status-Presets für v0.3.0
2026-09-27 Teams Away und Offline-Fallback für v0.3.1
